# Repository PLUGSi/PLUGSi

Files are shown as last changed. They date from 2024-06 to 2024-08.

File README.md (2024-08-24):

# PLUGSi

## Smart Modular Power Outlet

## By <a href="https://github.com/danidudabare">Danidu Dabare</a>, <a href="https://github.com/miniMagic-beep">Mihiran Wickramarathne</a>, <a href="https://github.com/DinukaMadhushan1234">Dunuka Madushan</a>, <a href="https://github.com/kavinsiriwardana">Kavin Siriwardana</a>, <a href="https://github.com/SanujaRupasinghe">Sanuja Rupasinghe</a> 

## Licence


## URLs for Original GitHub Repos
- [PLUGSi GitHub Organization](https://github.com/PLUGSi)
- [PCB Repository](https://github.com/PLUGSi/PCB)
- [Documentation Repository](https://github.com/PLUGSi/Documentation)
- [Enclosure Repository](https://github.com/PLUGSi/Enclosure)
- [Unity-AR Mobile App Repository](https://github.com/PLUGSi/Unity-AR-mobile-app)

## Demo
https://github.com/user-attachments/assets/67be34dc-b150-4223-8576-c7e0ef582f0e

## PCB
For Each moduel Seperate PCBs were created.

### Modules
- plug_base
- timer_module
- set_timer_module
- wireless_switch_module
- bluetooth_module

### Base and Moduels images

<table>
  <tr>
    <td><br>Base</td>
  </tr>
  <tr>
    <td><br>Wireless Module</td>
    <td><br>Set Timer Module</td>
  </tr>
  <tr>
    <td><br>Reprogrammable Timer Module</td>
    <td><br>Bluetooth Module</td>
  </tr>
</table>

**Open PCB files using Altium PCB design software.**

## Enclosure
### Key Design Decisions
1. **Compact & Futuristic**
2. **Uniform Design**
3. **Modular Architecture**

### Prototype Images
  
  

## AR app
The PLUGSi AR app, developed with Unity, integrates augmented reality via the Vuforia SDK for image targeting and uses the MQTT protocol for IoT communication, all coded in C#.

### Key Features
- **Unity & Vuforia**: Built on Unity with Vuforia SDK for AR, enabling image-based tracking.
- **MQTT Protocol**: Facilitates communication with a broker for IoT control.
- **Add-ons Integrated**:
  - UI Button Pack 2
  - Safe Area Helper
  - Lean GUI
  - Lean Touch

### Screenshots
<table>
  <tr>
    <td><br>Base</td>
  </tr>
  <tr>
    <td><br>Wireless Module</td>
    <td><br>Set Timer Module</td>
  </tr>
</table>

## Documents
All the documetns related to different stages are provided in this repo

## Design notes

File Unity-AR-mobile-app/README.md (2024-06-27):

# PLUGSi AR App

The AR app is designed for the IoT-based module in PLUGSi.

## Overview

The app is built with the Unity game development platform, meaning it is a mobile app developed in Unity. Augmented reality is included using the Vuforia SDK with image targeting (Image Targets represent images that Vuforia Engine can detect and track).

The MQTT protocol is used to communicate with a broker. It is coded in C# within the Unity app scripts.

## Add-ons Integrated

The Unity app integrates several free add-ons:
1. UI Button Pack 2
2. Safe Area Helper
3. Lean GUI
4. Lean Touch

## App Pages

The Unity app has three pages:
1. **Intro Page**: Continuously running a video.
2. **Digital Twin Page**: Accessible via a button on the Intro page, it activates your camera to find the targeted image.
3. **Control Page**: With the camera on, this page features two buttons:
   - **PLUGSi**: Turns on/off the device connected to the base when the IoT module is connected. It also changes the digital twin's color to red or green to indicate the current status (On or Off).
   - **Start**: Returns you to the Intro page.

## Screenshots

AR1
AR2
AR3

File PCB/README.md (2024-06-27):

# PCBs

## Overview
This repository contains the PCBs of plug base and the modules that can be used with this plug base such as a programmable timer, set timer, wireless switch, and Bluetooth module. 

## Project Structure
The repository is organized as follows:

- `plug_base/`: Contains PCB files of plug base that the various modules will connect to.
- `timer_module/`: Contains PCB files of reprogrammable timer module.
- `set_timer_module/`: Contains PCB files of set timer module.
- `wireless_switch_module/`: Contains PCB files of wireless switch module.
- `bluetooth_module/`: Contains PCB files of Bluetooth module.

## Plug_Base
### Components
- **CD4041**: CMOS quad NAND Schmitt trigger inverter, used likely as an inverter or buffer.
- **Relay**: Electromagnetic switch controlled by an electrical signal to open or close contacts.
- **Resistors**: 10kΩ and 100kΩ resistors to limit current flow.
- **Capacitors**: Used to store electrical energy (value not shown).
- **Power Supply**: Provides voltage of 3V and VCC.
- **Module Connection (P2 and P3)**: Interfaces where the different modules plug into the base.

## Timer_Module
### Components
- **CD4011BE**: Quad NAND gate IC, likely used in the timer functionality.
- **Resistors (R1 and R2)**: Limit current flow (values determine current).
- **Capacitor (C1)**: Controls the timing interval by charging and discharging.
- **Pulse Input**: Trigger for the timer.
- **Output (OUT)**: Controls a relay or switching device for the outlet.
- **Status LED**: Indicates the timer state (on or off).
- **Trigger Input**: Used to reset or start the timer.

## Set_Timer_Module
### Components
- **IC1 (555 Timer)**: Functions as a voltage-controlled timer in a monostable configuration.
- **Resistors (R1 and R2)**: Work with C1 to determine timer duration.
- **Capacitor (C1)**: Sets the timer duration by controlling charge/discharge cycles.
- **Push Button (SW1)**: Trigger to initiate the timer.
- **LED1**: Visual indicator of timer status.
- **Output (OUT)**: Controls a relay or switching device for the outlet.

## Wireless_Switch_Module
### Components
- **IC1 (CD4017BE)**: CMOS IC with decade counter/divider stages, used to decode wireless signals.
- **Resistors (R1, R2, R3, R4)**: Limit current and set voltage levels.
- **Capacitor (C1)**: Filters noise on the power supply line.
- **Receiver (DI)**: Antenna or receiver circuit for the wireless signal.
- **Output (OUT)**: Controls a relay or switching device for the outlet.
- **Status LED**: Indicates the receiver module state (on or off).

## Bluetooth_Module
### Components
- **Microcontroller (U1)**: Controls the Bluetooth module and communicates with other devices.
- **Crystal (Y1)**: Provides precise oscillating signal for synchronization.
- **Resistors**: Limit current, set voltage levels, and bias transistors.
- **Capacitors**: Filter power supply, store energy, and provide stability.
- **Inductor (L1)**: Part of the matching circuit for the Bluetooth antenna.
- **Bluetooth Antenna**: Transmits and receives Bluetooth signals.
- **Status LED**: Indicates Bluetooth module state (powered on, connected, etc.).
- **Connection Pins (PBO - P5)**: Connect the Bluetooth module to the main plug base unit.

## Usage
### **Navigate to the Desired Module/PlugBase**:
  1. [`Plug Base`](./1.%20Plug%20Base)
  2. [`Reprogrammable Timer`](./2.%20Reprogrammable%20Timer)
  4. [`Set Timer`](./3.%20Set%20Timer)
  5. [`Wireless Switch`](./4.%20Wireless%20Switch)
  6. [`Bluetooth module`](./5.%20Bluetooth%20module)

### **Open the PCB Files**:
Use Altium PCB design software to open files.

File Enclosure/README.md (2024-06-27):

# Enclosure

Since the PLUGSi consists of main components: Base and Modules, and considering modular architecture, the following decisions were made:

1. **Try to make it as small as possible**
   - Give it a compact futuristic look
2. **Uniformity in Design**
   - All sides in the Base and Modules are the same size and cubic shape
   - Must be able to connect modules over the base and modules over modules
3. **General Architecture**
   - Modules have a general architecture with the same size as the Base
   - Design must accommodate multiple modules with minor changes to fit different functionalities

The initial design is available on [GrabCAD](https://grabcad.com/library/plugsi-1). We were unable to complete the design due to imperfections of 3D printers and the inability to make a very compact design by hand. For the ports, it should be 4 pin ports. Initial ideas were to make ports and 3D print them (which was hard to do). So we thought about other options like [4-Pin magnetic POGO connections](https://kamami.pl/en/pogo-pin/1181255-pair-of-4-pin-magnetic-connectors-straight.html) and the [4-Pin magnetic POGO connections 3D models](https://grabcad.com/library/pogo-pins-ports-1). For the prototype, we used 4-Pin JST connections.

We have designed a prototype version of the PLUGSi enclosure which is done by laser cutting of acrylic.

## Prototype Images
Images taken from SolidWorks and Rendered images from blender are available here.








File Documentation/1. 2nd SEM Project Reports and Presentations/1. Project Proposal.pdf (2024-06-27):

# Engineering Design Project

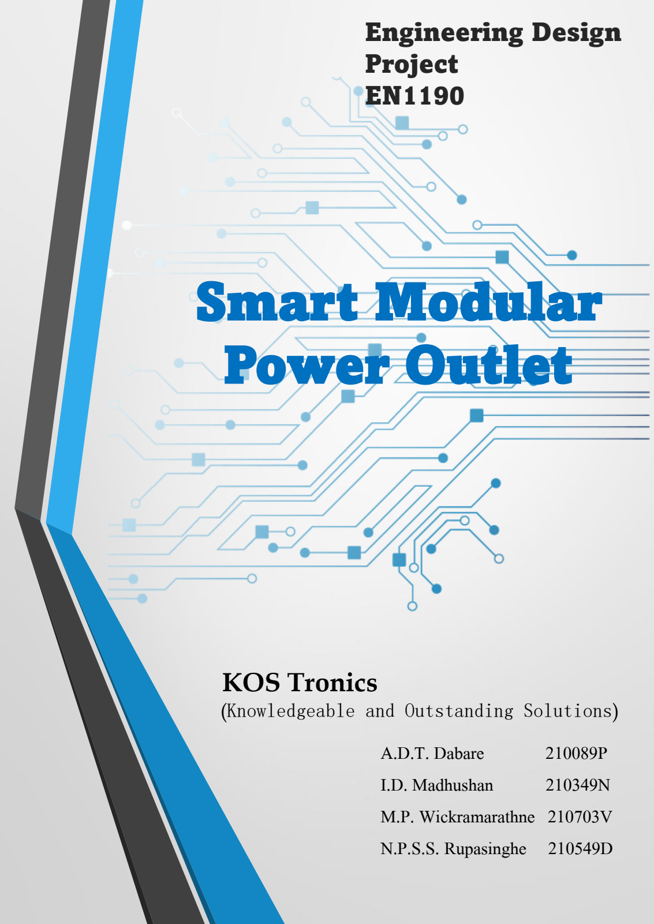
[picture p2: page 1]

EN1190

# KOS Tronics

### (Knowledgeable and Outstanding Solutions)

# Smart Modular Power Outlet

A.D.T. Dabare | 210089P
I.D. Madhushan | 210349N

# M.P. Wickramarathne 210703V N.P.S.S. Rupasinghe 210549D

### Problem

The current world is embracing smart technologies but majority of the devices we encounter does not have those capabilities. And there are no smart power outlets that are up to a level to be called smart. The existing solutions are neither customizable, repairable nor upgradable and does not have a robust design. When purchasing smart outlets, users currently have to pay for all the features even though they only need a specific function.

### Solution

The solution we propose is a smart modular power outlet to which the user can attach modules as needed. In our proposed solution, users can get the smart power outlet base for a low price and then add up the required and additional modules as needed.
Example : If the user needs to turn on a fan via the Bluetooth, then they have to buy a smart fan(quite expensive) or to buy an existing smart power outlet which has so many other additional features that are not needed for the purpose.

Manufacturing a purpose specific solution can be costly because number of products is small but manufacturing a general solution that can be made purpose specific is ideal for that problem.

### Working Principle

The device is consisted of two main parts.
- Main Base
- Modules
Main Base will be connected to a power outlet and any utility can be connected to it. Main base will control the AC supply to the utility and provide power to modules. Main base will have a port(interface) to communicate with the modules.
Modules can be attached to and detached from the Main Base. Modules will control the state of the Main base. Modules can have a variety of abilities based on their design. Multiple modules can be connected to the same Main Base.

Some examples for Modules
- Bluetooth Module
- Timer Module
- PIR Module
- Temperature sensing Module

### How it stands out

- Customizability
- Comparatively low cost
- Can be a tool for other developments
- High Repairability
- Can be made purpose specific

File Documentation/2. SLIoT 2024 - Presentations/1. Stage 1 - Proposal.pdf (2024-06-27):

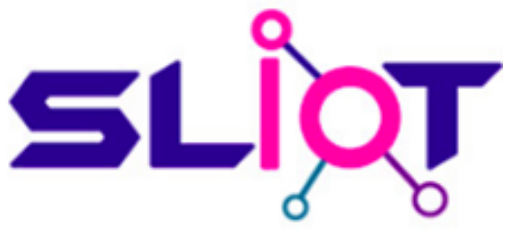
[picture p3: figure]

# PLUGSi Smart Modular Power Outlet

# Project Proposal

Team Name | PLUGSi
Category | UNDERGRADUATE
Theme | INDUSTRY 4.0

# Problem Definition

## Introduction

Our team noticed that the existing power outlets are not advanced enough to match the level of technological advancement in the current world. Although there are many smart appliances, power outlets that can actually be called smart are not available on the market. The problem we identified is that the existing power outlets do not have customizable add-ons such as Bluetooth, Wi-Fi, Reprogrammable Timers, Set Timers, etc. nor intelligent decision-making abilities. They either cater to only their core function or have add-ons that come with it originally eliminating the ability to customize them according to the needs of the user making them highly expensive. Therefore, we conducted a survey to get detailed user inputs and what follows are the reasons for the existing options to be disliked by users. We aim to resolve the following concerns by addressing our main identified problem emphasized above.

We conducted a survey and following are the results.

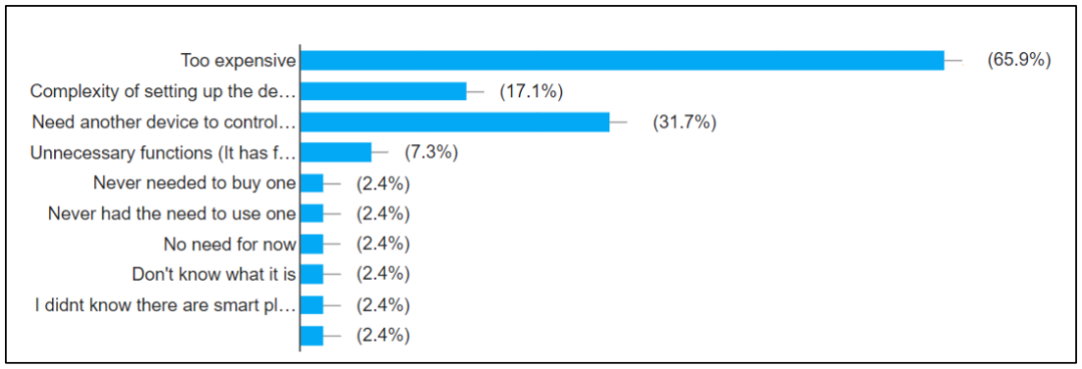
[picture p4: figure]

## Problem Analysis

In the rapidly advancing landscape of smart technologies, where IoT and automation are transforming daily life, the stagnation in smart power outlets is a bottleneck. The identified problem holds implications across various sectors: both domestic and industrial. Domestic consumers are increasingly adopting smart home technologies, yet the current limitations in smart power outlets hinder their full potential. In industrial settings, the lack of advanced power outlets results in missed opportunities for automation and optimization. By incorporating IoT through a mobile application into smart power outlets, we can enable dynamic communication, allowing for advanced automation and intelligent decision-making based on real-time data. Our proposed solution aligns with the paradigm of Industry 4.0 as we look into Integrating IoT, AI, and automation into the development of customizable smart power outlets. AI algorithms can learn user behavior, optimize energy usage, and adapt to changing patterns.

# Proposed Solution

## Proposed Product

The product consists of two main parts.
- Power Base
- Modules

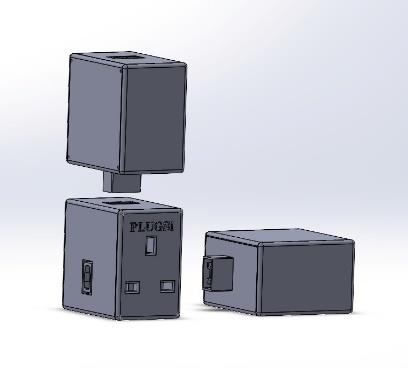
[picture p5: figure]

Modules can be attached to and detached from the Power Base. Modules control the state of the power base. They can have a variety of abilities based on their design. Multiple modules can be connected to the same Power Base. Bluetooth Module, Reprogrammable Timer Module, Set Timer Module, and Wireless Switch are some examples for Modules.

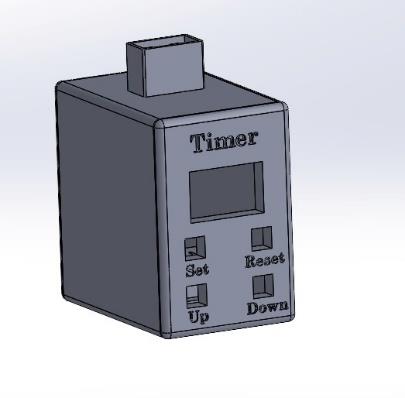
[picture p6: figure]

Power Base is connected to a power outlet and any utility (device) can be connected to the Power Base. It controls the AC supply to the device and provide power to modules. Power Base has ports(interfaces) to communicate with the modules.

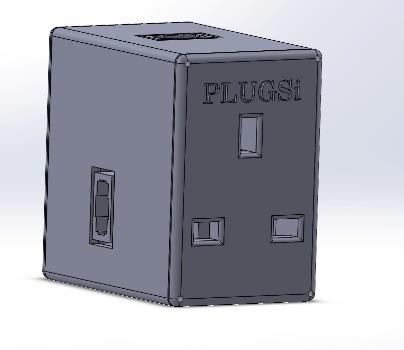
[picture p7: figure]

## Uniqueness of the Solution

In our solution, users can choose the modules that they need rather than paying for all the unnecessary functions. We can provide instructions as to how the Power Base works and the requirements that a module needs so that anyone can make their own modules. Further, it uses a standardized communication protocol, ensuring seamless integration. Its affordable power base provides a cost-effective entry point, while allowing third parties to develop modules. Its unique modular design enables users to swap modules based on their interests or changing needs, promoting adaptability. This is an eco-friendly solution as this minimizes electronic waste. In essence, the Smart Modular Power Outlet redefines user experience with affordability, adaptability, modularity, and customizability.

# Technical Overview and Implementation

## Technical Details

The module is designed to issue a command using a pulse signal, and it performs a status check prior to generating the pulse signal. In the event that the power base has reserved a pulse, the base modifies the current state of the relay. This functionality is achieved through the implementation of a pulse-based communication protocol and the integration of status monitoring and relay control mechanisms within the module's architecture.

Module’s hardware will be based on their own designs to achieve the required outcome. All of them would share a mechanism to check the base status and generate the pulse.

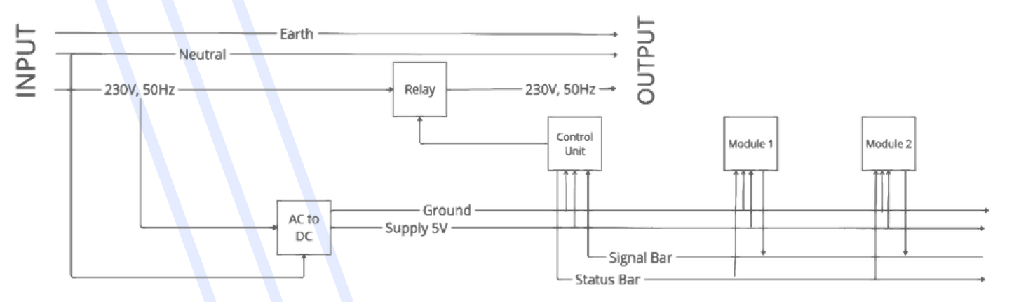
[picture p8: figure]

# User Scenario

Scenario 1
Industrial facilities often require control over the power supply to numerous machines for maintenance, energy management, and process optimization. Currently, existing options fall short:
- They have to rely on existing smart plug which comes with load of unnecessary features with a high price
- They have to build a power outlet from the scratch

Solution: PLUGSi, the modular smart plug, revolutionizes industrial machine control with its flexible and scalable approach with low cost. They just have to use PLUGSi base with the Bluetooth module. Even it is possible to upgrade PLUGSi when needed with such as IoT features, timers etc.

Scenario 2
Thaveesha wants to control his water pump by a remote control and turn it off automatically after 10 minutes. There is no popular solution for him in current market. He has to buy something which can be very expensive and not suitable to the scenario.

Solution: Thaveesha only has to get the PLUGSi base, Timer module, And IR module with Remote controller. And now he has achieved his goal. Hooray. He has the possibility of upgrading to or use PLUGSi with a completely different use case.

Scenario 3
The power outlet modules can be equipped with energy monitoring capabilities. Residents can track and analyze the energy consumption of individual devices plugged into these outlets through a dedicated mobile app or a centralized smart home hub using digital twin technology.

Scenario 4
Some power outlet modules can include built-in occupancy sensors. If no motion is detected in a room for a specified period, the outlets can automatically cut power to connected devices to prevent unnecessary energy consumption and reduce the risk of electrical fires. Smart outlets can be integrated with home security systems. For example, when the security system is armed, the outlets can automatically cut power to non-essential devices, creating the appearance that nobody is home.

# Team Details

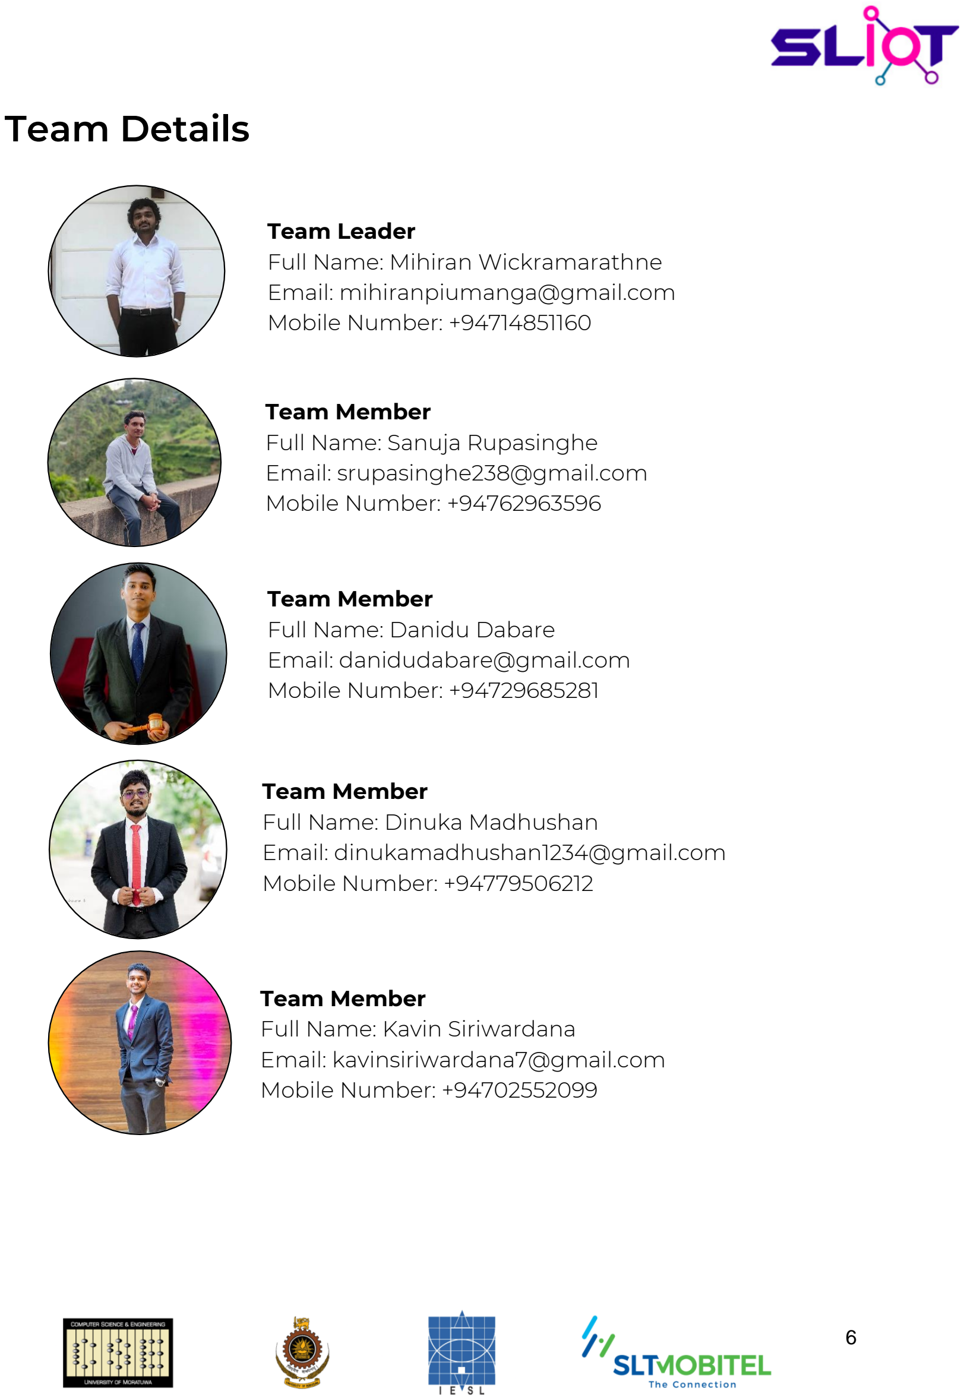
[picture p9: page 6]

Team Leader
Full Name: Mihiran Wickramarathne Email: mihiranpiumanga@gmail.com Mobile Number: +94714851160

Team Member
Full Name: Sanuja Rupasinghe Email: srupasinghe238@gmail.com Mobile Number: +94762963596

Team Member
Full Name: Danidu Dabare
Email: danidudabare@gmail.com Mobile Number: +94729685281

Team Member
Full Name: Dinuka Madhushan
Email: dinukamadhushan1234@gmail.com Mobile Number: +94779506212

Team Member
Full Name: Kavin Siriwardana Email: kavinsiriwardana7@gmail.com Mobile Number: +94702552099

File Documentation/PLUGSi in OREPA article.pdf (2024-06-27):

# PLUGSi

The Modular Smart power outlet

Begin
PLUGSi is a way that can be used to revolutionize the way we think about power outlets

Introduction - Who We Are
We are 4 undergraduates from the Electronic and Telecommunication Department of the University of Moratuwa. For our Electronic Design Project module, We proposed this Idea and executed it.

Philosophy - modularity
Modularity is a philosophy not used in the current smart power outlet industry. You may see a cube-looking thing. called a “smart power outlet” (which is indeed smart) containing everything inside it (Maybe Alexa, Google Home, timers, Bluetooth Controllers, Wi-Fi controllers) to control a few things. Your Table Lamp, AC, something else. Some are Product Specific, and Some give additional functionality that you’ll never use but you paid extra money for it.

Use Case
Assuming you are a smart plug user, one day your girlfriend comes to your home, and She wants to control the light that is plugged into your smart plug only using Bluetooth. What if your Smart plug does not support that functionality? You have few options. Change your Girlfriend 😅 (be careful) or buy a new smart plug that has Bluetooth support 💰 (may be somewhat expensive).
But with PLUGSi You have to do neither. Because we are giving you another option.

Functionality - base, modules, and apps
PLUGSi consists of 2 main parts. Base and modules (timers module, Wireless module, Wi-Fi modules, Bluetooth modules, IOT-based modules, Alexa Modules, reprogrammable Modules, etc) You can plug modules over the base and modules over other modules, it's your choice. Modules are the ones that add functionalities to the base. Users can attach detach and reattach as they wish. That other option is if you already have a PLUGSi base. Just buy a Bluetooth module. Save your money and your girlfriend!

We made a prototype for the demonstration - MVP

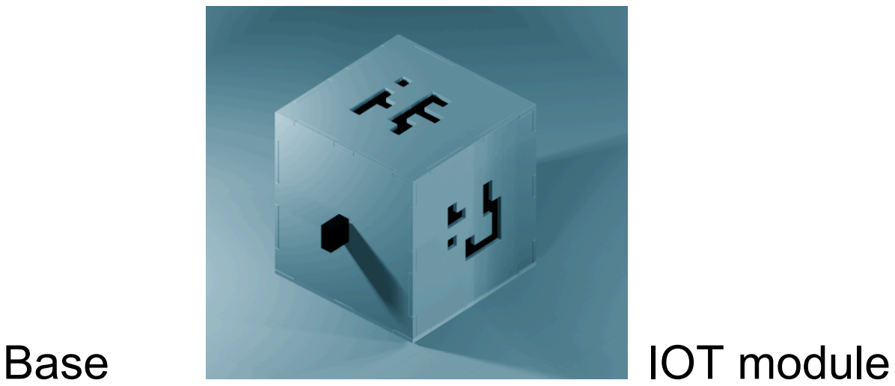
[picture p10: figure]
Base; IOT module
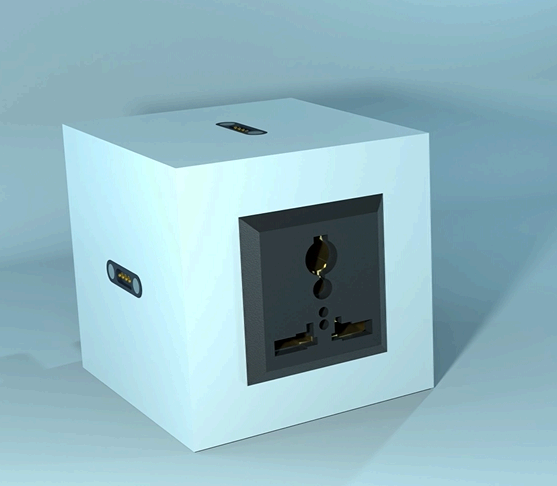
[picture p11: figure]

Base PCB

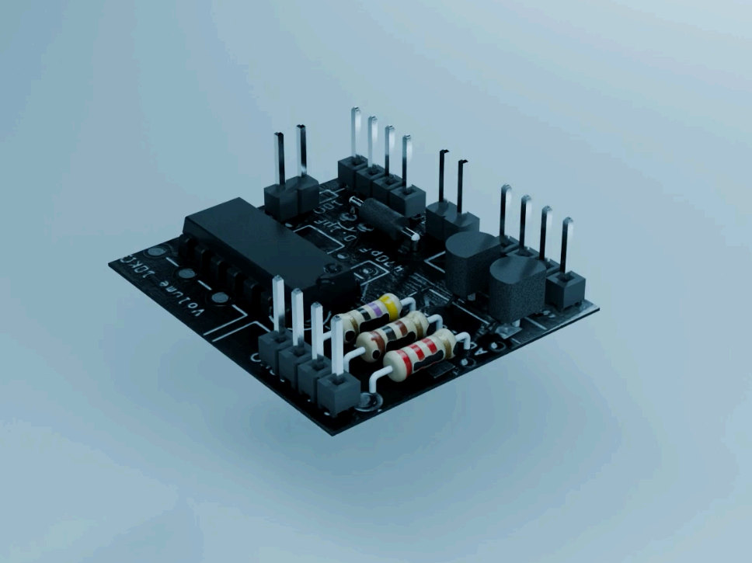
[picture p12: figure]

Architecture of the product

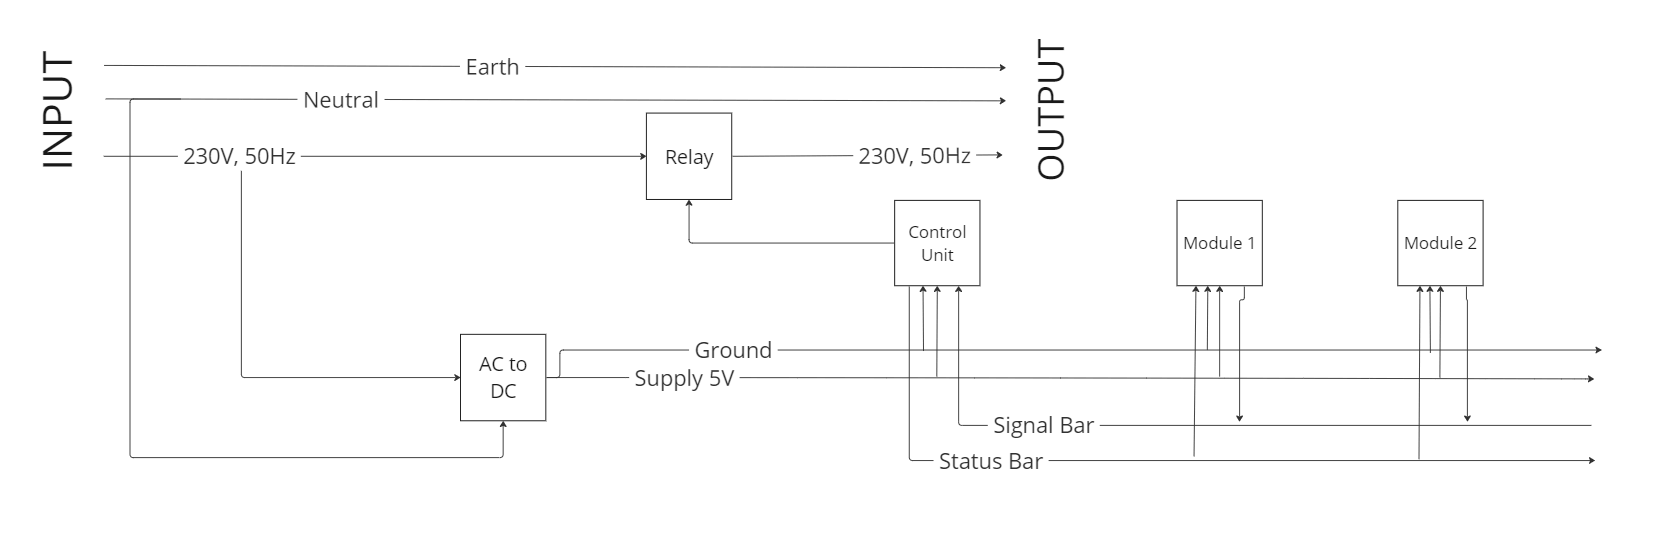
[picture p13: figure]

About Modules

For the Bluetooth module, we will provide the users with a Bluetooth app from Play Store.
For the IOT module, we will provide the users with a web dashboard, and an App that gives a brand-new user experience (a Digital twin) by giving them a Virtual representation of the IOT module with Augmented reality.
We made timer modules also (with 5min Fixed timer and timer that we can select the time)

this is for IOT app

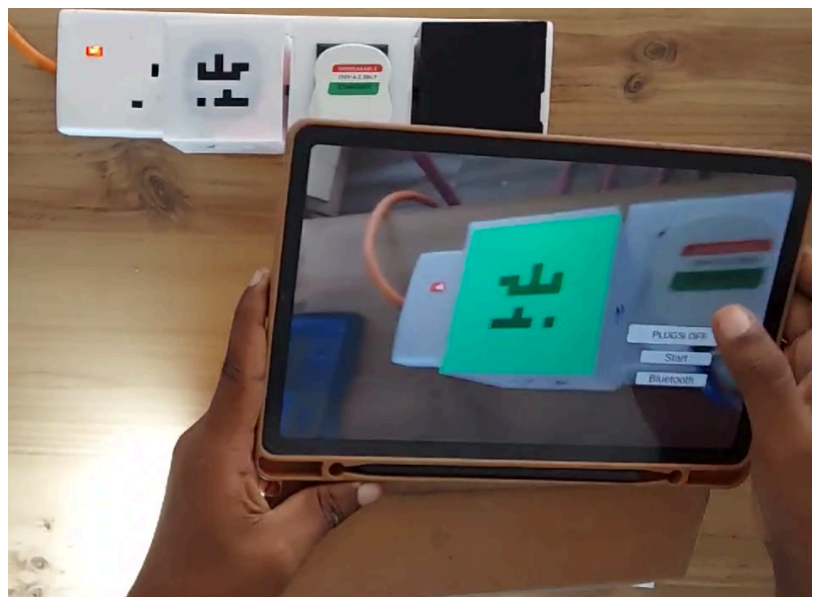
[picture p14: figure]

(This is not the end product. This is just for the prototyping MVP)

For the IOT part, we are using the standard communication protocol MQTT which is used in the IOT industry. We made a pulse communication protocol that communicates between the Base and Modules from scratch.

For whom did we make it?
Current smart plugs focus on just only smart home systems and automation. Of course, that is one of our targets. And we will give a safe environment to the DIY community so they can develop over our PLUGSi.
You may have seen that there are hundreds of thousands of Videos on YouTube tutorials that teach how to use Arduino-related things, relays and so many things to make your home smart. If you are a parent you may not allow your child to do those things because there is an issue about the safety of your child. Because the child has to work with an AC line which needs good guidance.
But with PLUGSi we are providing a fully functioning Base. No worries about the AC line, Even a 5-year-old can build and automate their house by buying a Base and Reprogrammable Module. We will provide them with a simple IDE so they can drag and drop the functions and program that module safely and do anything that they like.
And 3rd parties will be able to make modules and then they can be a part of a the PLUGSi ecosystem.

End
To achieve infinite modularity, simplicity, unlimited customizability, and adaptability there is no

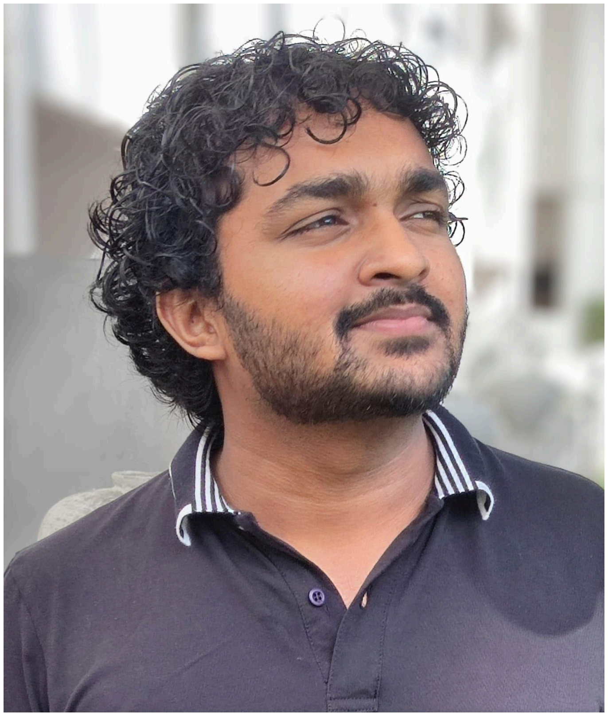
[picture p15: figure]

way other than PLUGSi.

Our Team

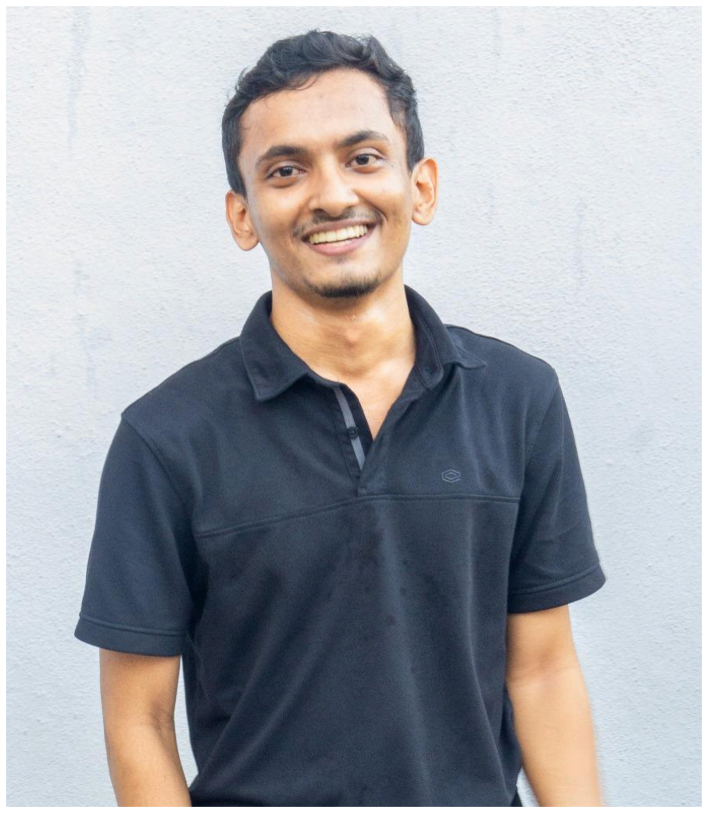
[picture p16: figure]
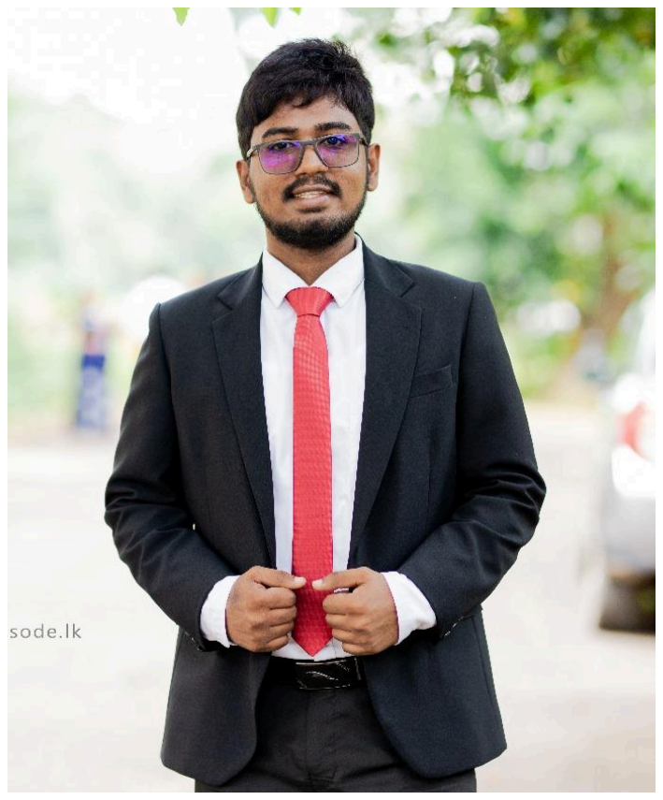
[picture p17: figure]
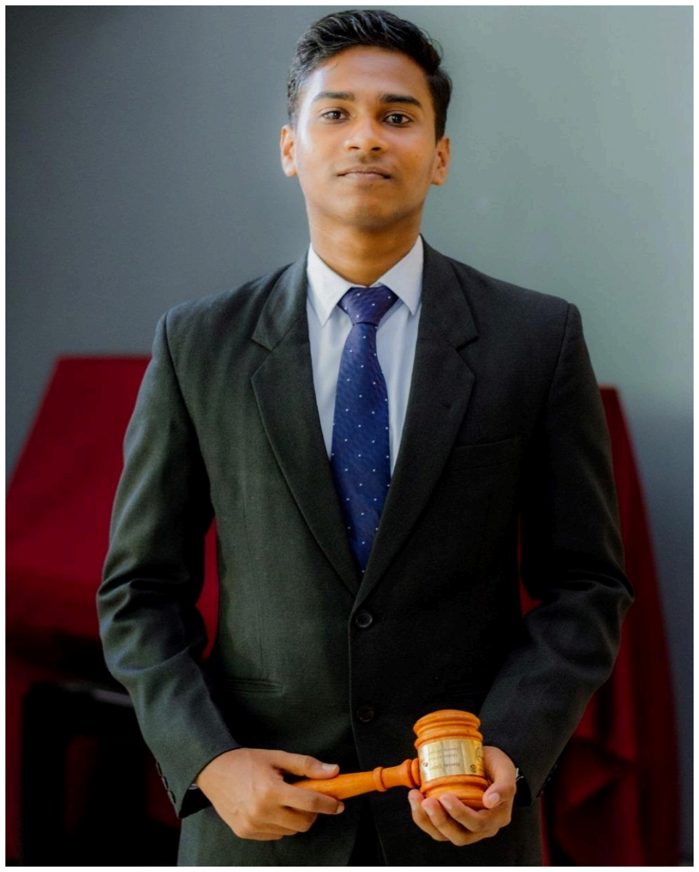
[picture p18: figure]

Mihiran | Sanuja | Dinuka | Danidu

Achievements
Finalists at INSL Sri Lanka Business Stage 2024 Semi-Finalists at SLIoT Challenge 2023

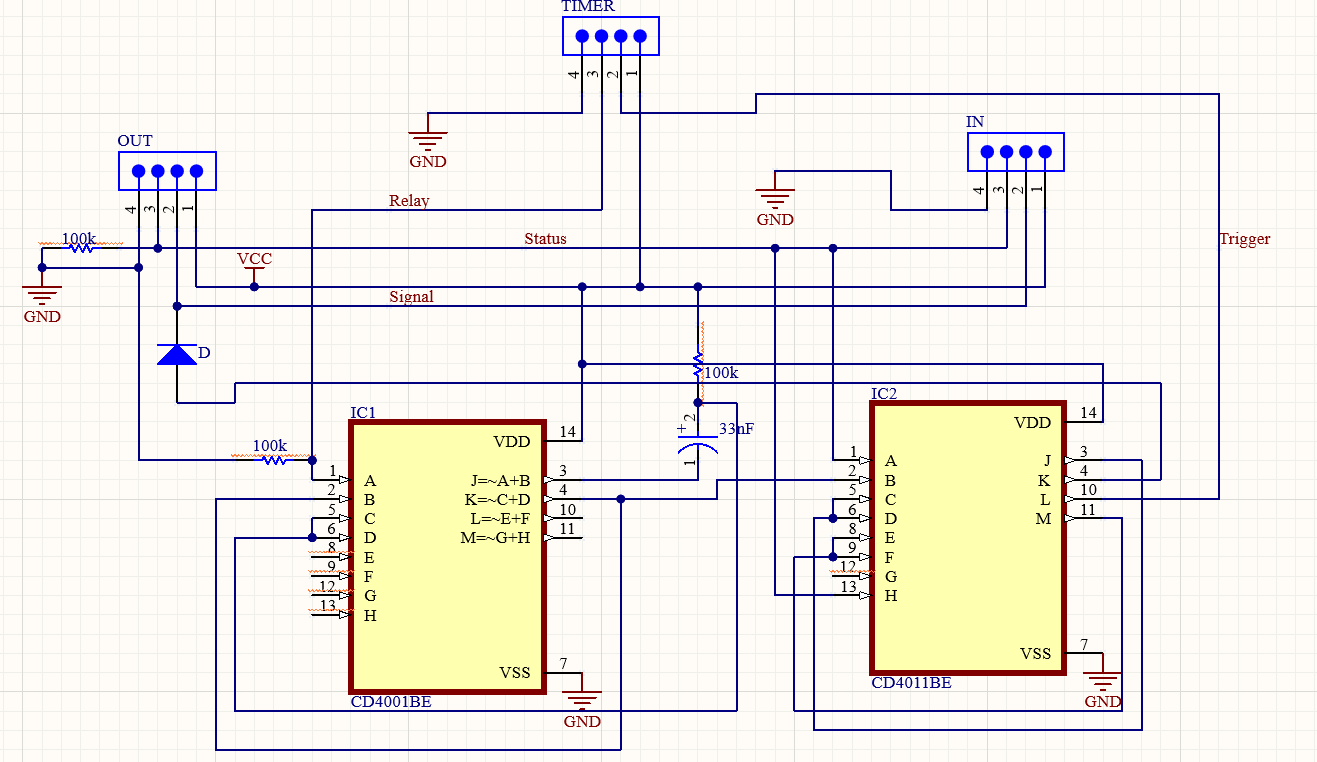
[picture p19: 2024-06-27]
PCB/2. Reprogrammable Timer/Timer Schematic.png

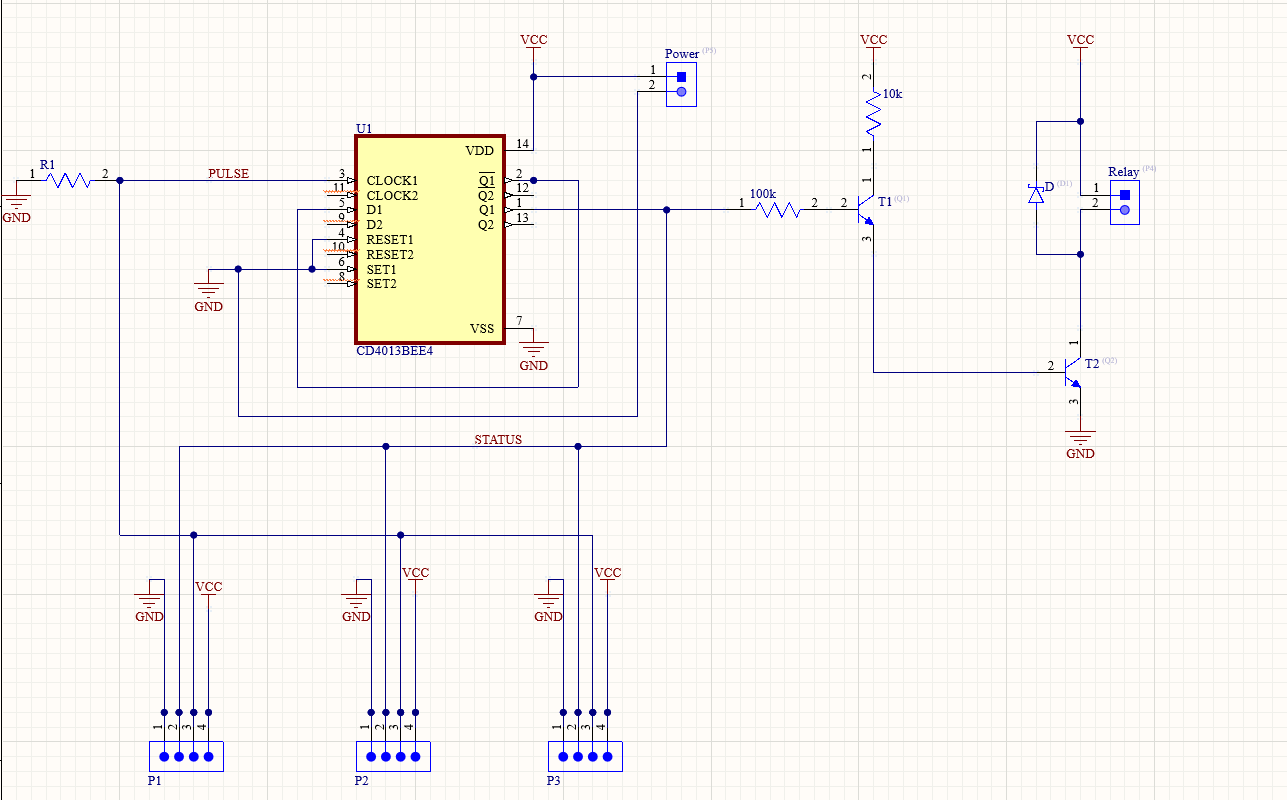
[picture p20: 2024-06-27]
PCB/1. Plug Base/Plug Base Schematic.png

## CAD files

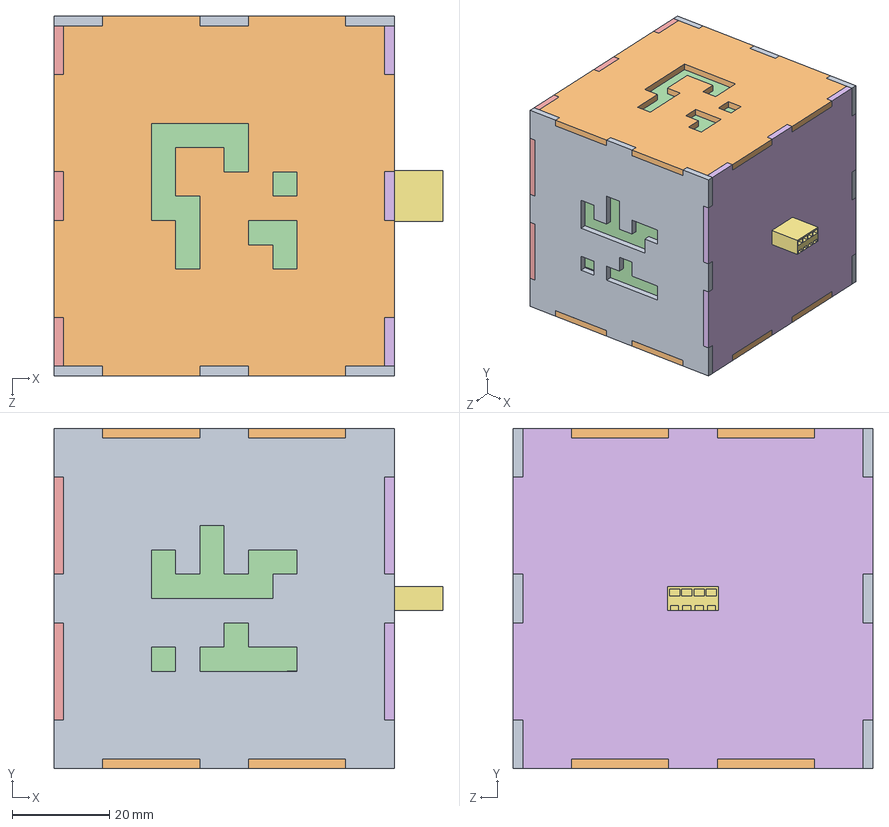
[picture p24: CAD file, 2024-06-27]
Enclosure/Module/Module_Assem.SLDASM
80.0 x 70.0 x 74.0 mm
Module_Front x 2
Module_TB x 2
fixer x 4
Black_Cover x 4
Module_LR_Female
Module_LR_Male
port_1
port_2

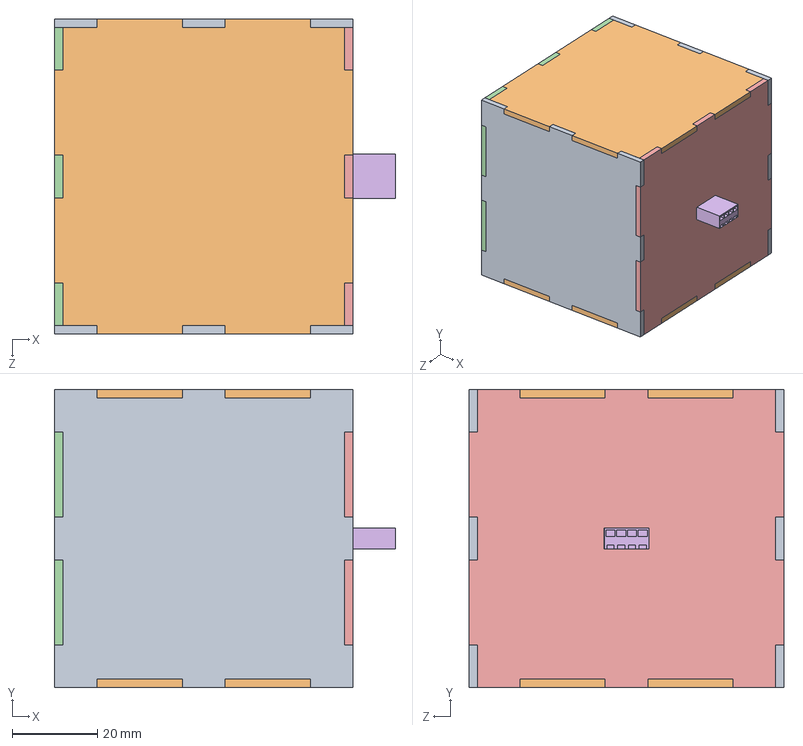
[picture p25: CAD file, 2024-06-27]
Enclosure/Module_Normal/Module_Assem.SLDASM
80.0 x 70.0 x 74.0 mm
Module_Front x 2
Module_TB x 2
fixer x 4
Module_LR_Female
Module_LR_Male
port_1
port_2

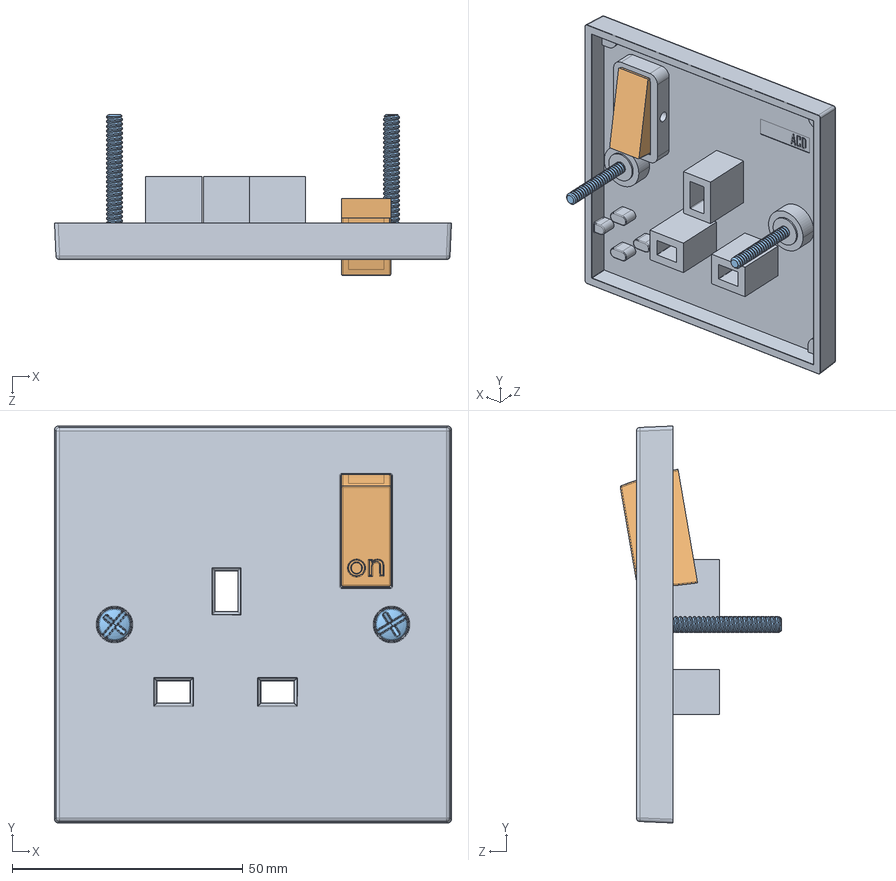
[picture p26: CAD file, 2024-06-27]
Enclosure/Base/UK plug/Plug Socket UK 13 STEP.STEP
86.0 x 86.0 x 35.0 mm
Plug Fascia
Switch
Main Screw x 2

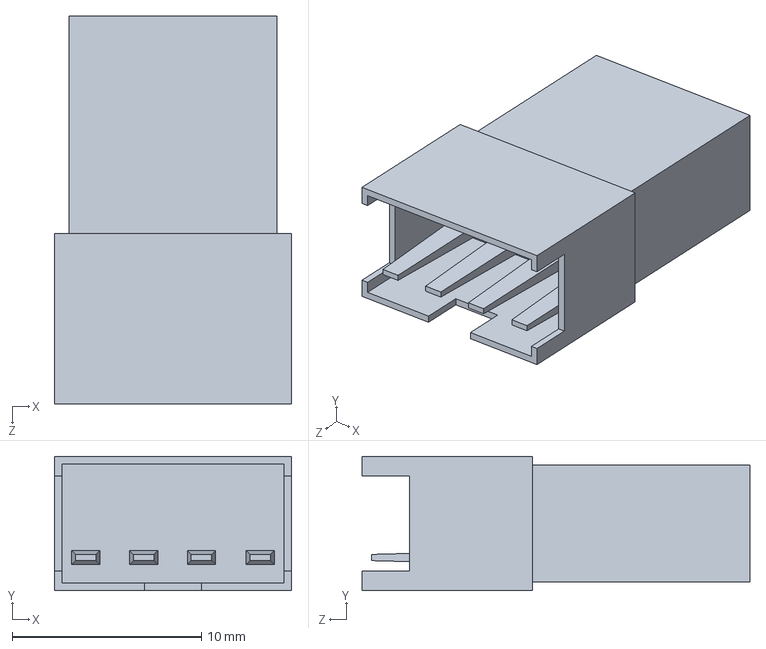
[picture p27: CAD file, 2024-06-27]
Enclosure/Module/port_2.SLDPRT
12.5 x 7.10 x 20.5 mm

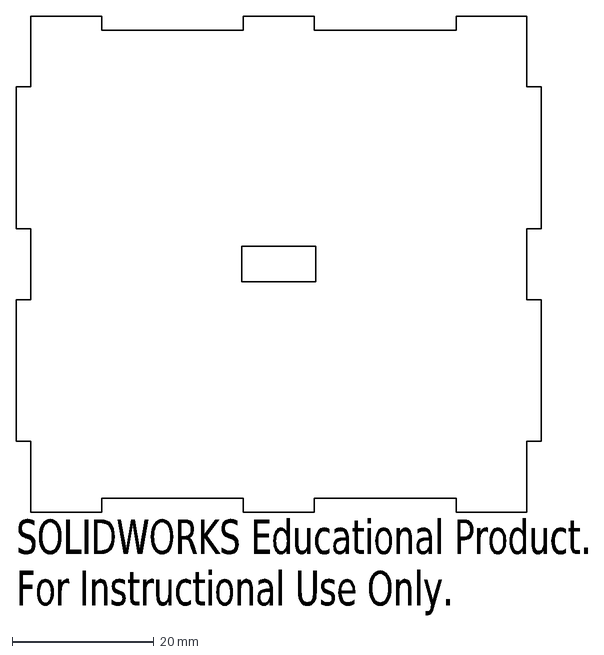
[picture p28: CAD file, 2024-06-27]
Enclosure/Module_Normal/DXF/Black/Module_LR_Male-1.DXF
SOLIDWORKS Educational Product.
For Instructional Use Only.

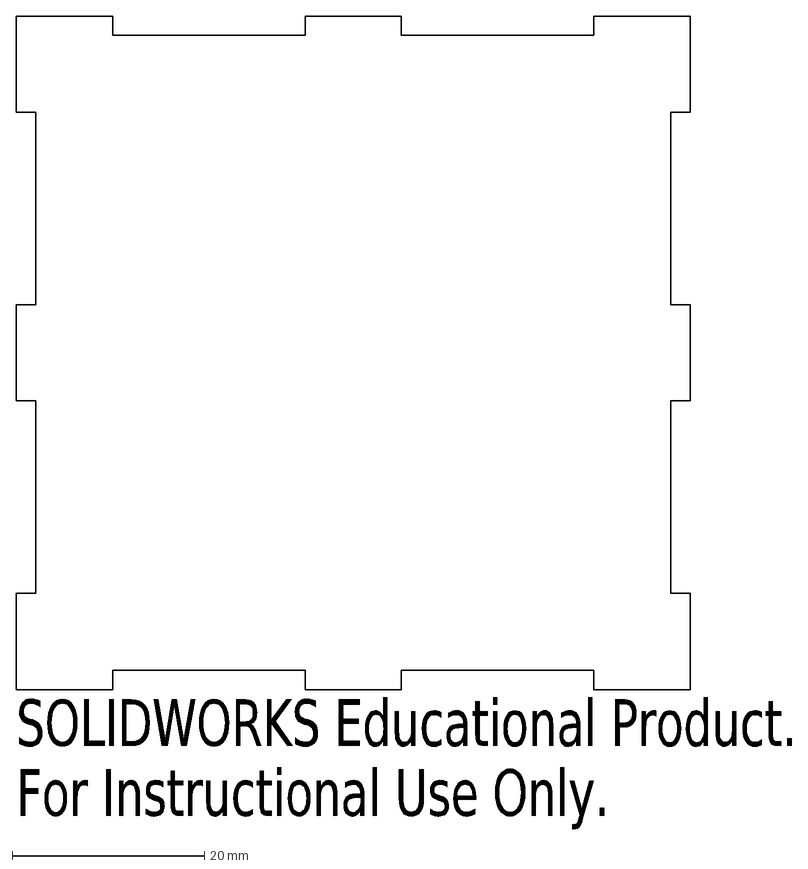
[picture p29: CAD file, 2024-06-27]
Enclosure/Module_Normal/DXF/White/Module_Front-2.DXF
SOLIDWORKS Educational Product.
For Instructional Use Only.

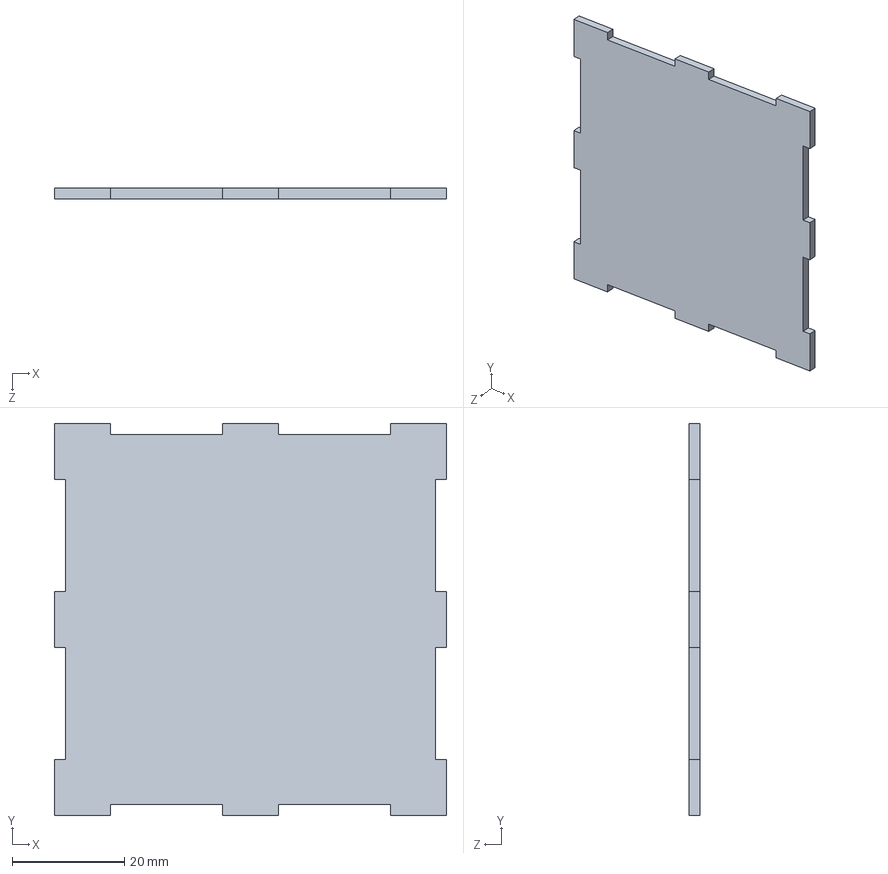
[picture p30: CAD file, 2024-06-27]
Enclosure/Module_Normal/Module_Front.SLDPRT
70.0 x 70.0 x 2.00 mm

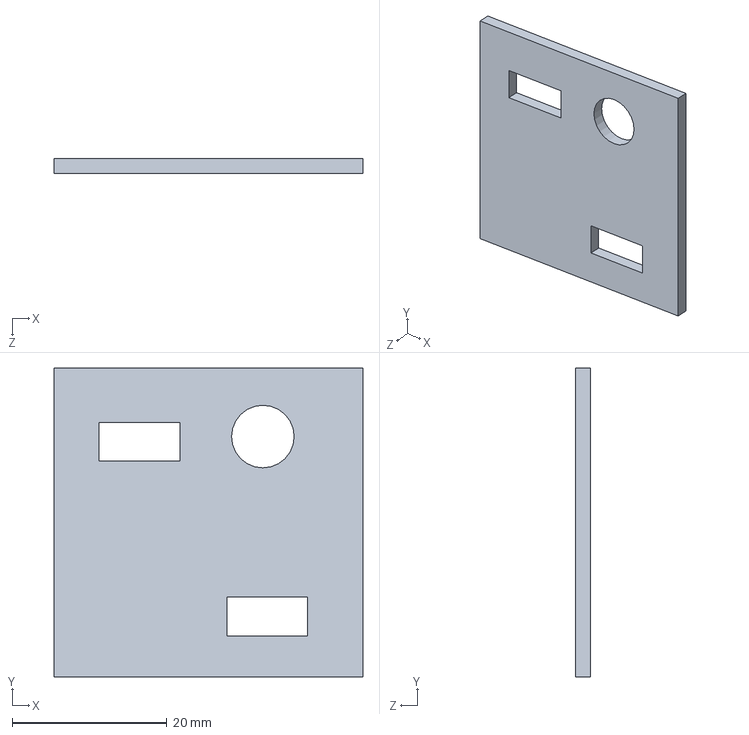
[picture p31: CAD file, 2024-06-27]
Enclosure/Module_Normal/test/Part1.SLDPRT
40.0 x 40.0 x 2.00 mm

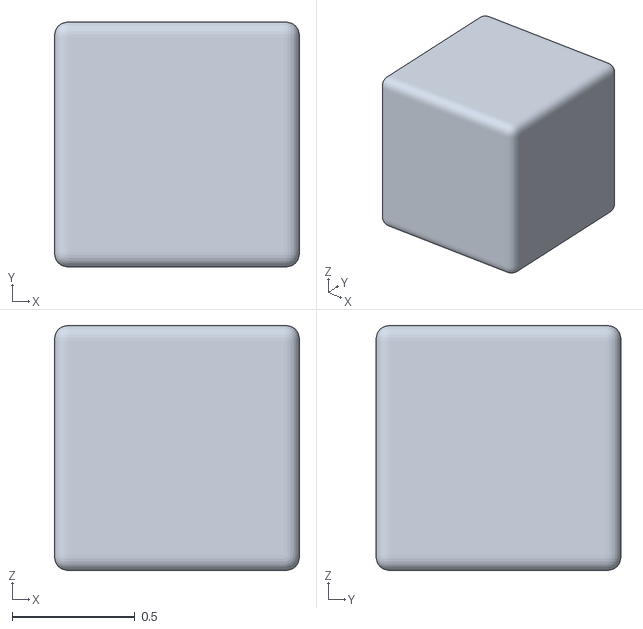
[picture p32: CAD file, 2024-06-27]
Unity-AR-mobile-app/PLUGSi_AR_App/Assets/Plugins/CW/LeanCommon/Examples/Meshes/RoundedCube.obj
1.00 x 1.00 x 1.00

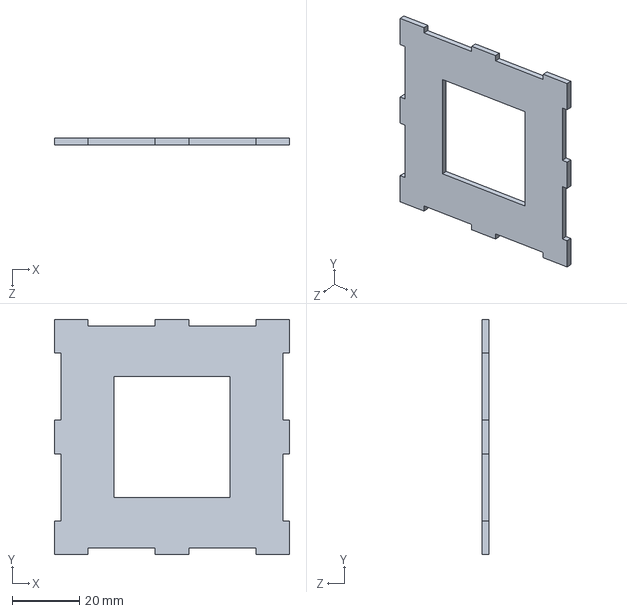
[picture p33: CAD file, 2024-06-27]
Enclosure/Base/Base_Front.SLDPRT
70.0 x 70.0 x 2.00 mm

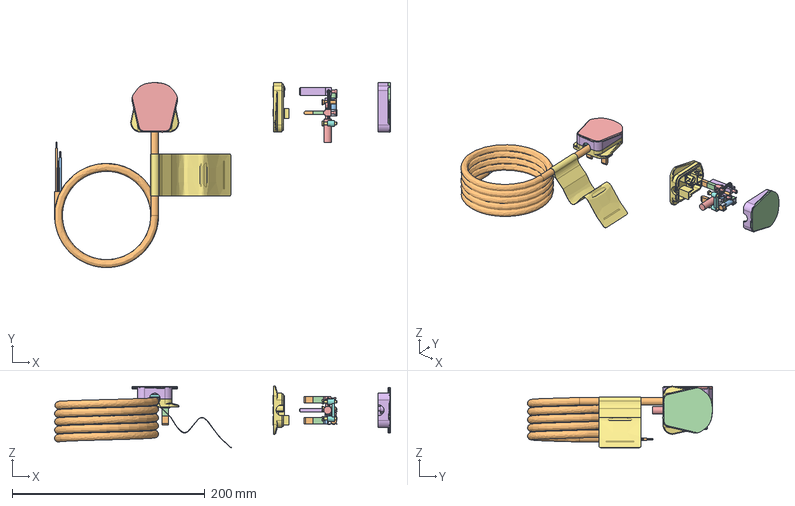
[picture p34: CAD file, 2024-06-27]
Enclosure/Base/UK plug/UK 3 PIN PLUG.stp
348.5 x 192.0 x 64.0 mm

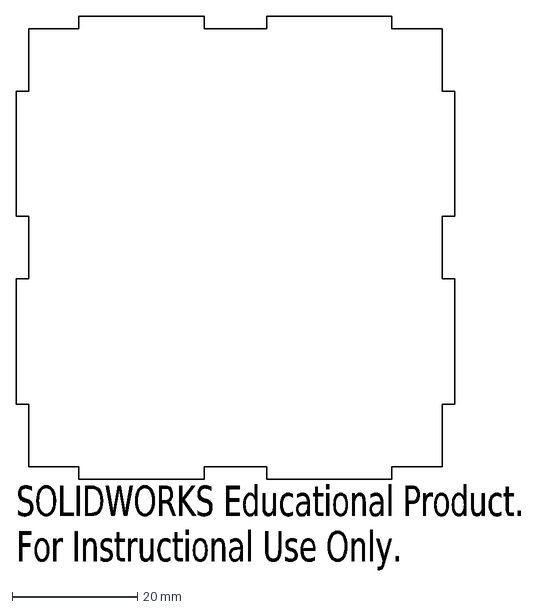
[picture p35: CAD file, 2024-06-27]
Enclosure/Module_Normal/DXF/Black/Module_TB-2.DXF
SOLIDWORKS Educational Product.
For Instructional Use Only.

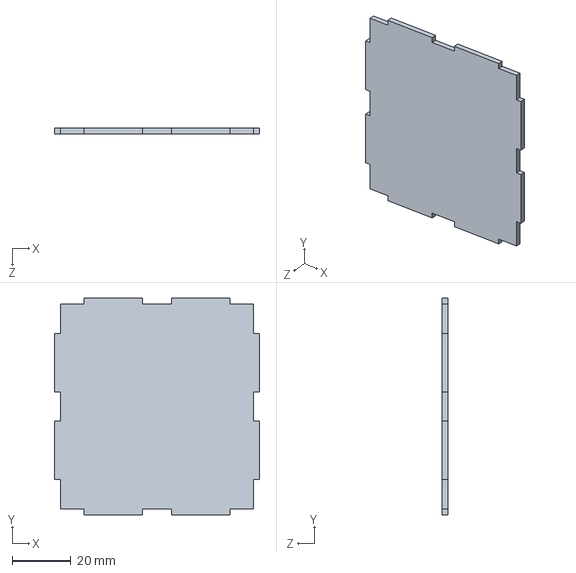
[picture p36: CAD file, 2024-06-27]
Enclosure/Module_Normal/Module_TB.SLDPRT
70.0 x 74.0 x 2.00 mm

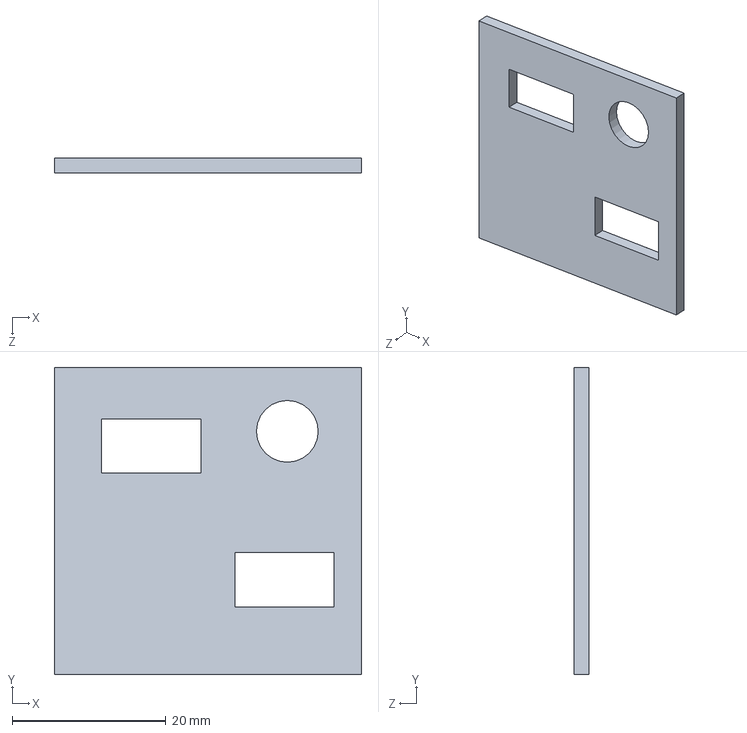
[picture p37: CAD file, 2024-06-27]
Enclosure/Module_Normal/test/Part3.SLDPRT
40.0 x 40.0 x 2.00 mm

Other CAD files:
Enclosure/Base/Base_LR.SLDPRT
Enclosure/Module/Module_LR_Female.SLDPRT
Enclosure/Base/220ACto5VDC.SLDPRT
Enclosure/Base/Base_Back.SLDPRT
Enclosure/Base/Base_LR_Pogo_Port.SLDPRT
Enclosure/Base/Base_Plug_Front.SLDPRT
Enclosure/Base/Base_TB - Copy.SLDPRT
Enclosure/Base/Base_TB.SLDPRT
Enclosure/Module/Black_Cover.SLDPRT
Enclosure/Module/Module_Back.SLDPRT
Enclosure/Module/Module_Front.SLDPRT
Enclosure/Module/Module_LR.SLDPRT
Enclosure/Module/Module_LR_Male.SLDPRT
Enclosure/Module/Module_TB.SLDPRT
Enclosure/Module/fixer.SLDPRT
Enclosure/Module/port_1.SLDPRT
Enclosure/Module_Normal/Black_Cover.SLDPRT
Enclosure/Module_Normal/DXF/Black/Module_LR_Female-1.DXF
Enclosure/Module_Normal/DXF/White/Module_LR_Female-1.DXF
Enclosure/Module_Normal/Module_Back.SLDPRT
Enclosure/Module_Normal/Module_LR.SLDPRT
Enclosure/Module_Normal/Module_LR_Female.SLDPRT
Enclosure/Module_Normal/Module_LR_Male.SLDPRT
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

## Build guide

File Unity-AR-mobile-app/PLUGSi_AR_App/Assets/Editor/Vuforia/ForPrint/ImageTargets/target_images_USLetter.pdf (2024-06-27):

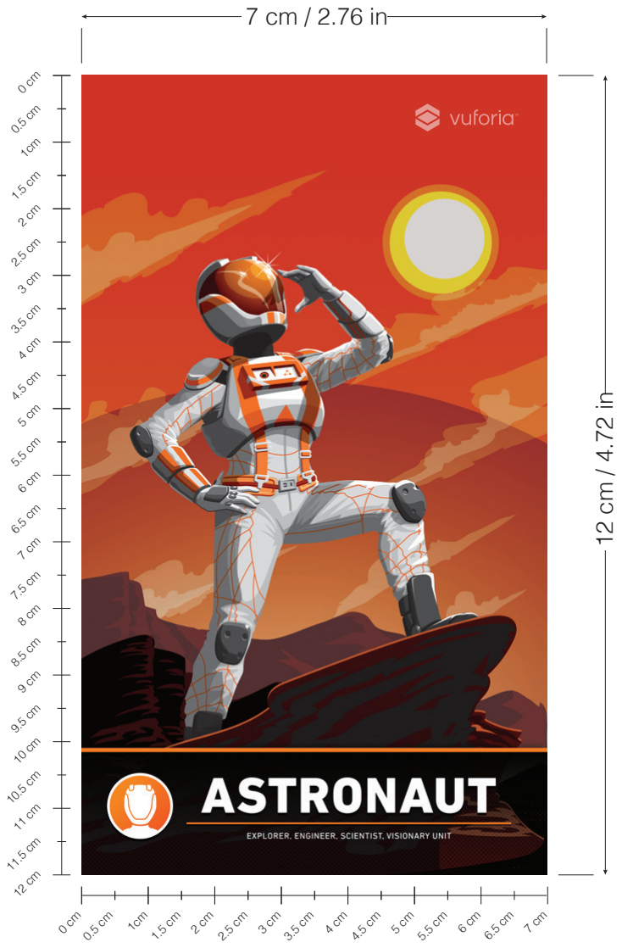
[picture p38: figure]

©2017 - 2018 PTC Inc. All rights reserved.

For best results, please print without scaling.

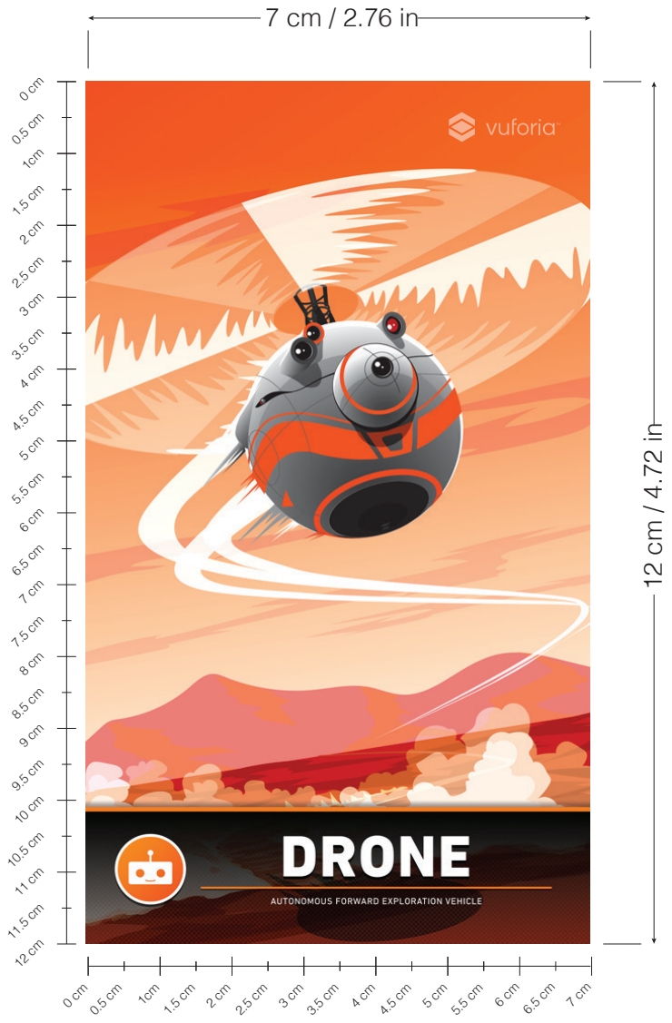
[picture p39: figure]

©2017 - 2018 PTC Inc. All rights reserved.

For best results, please print without scaling.

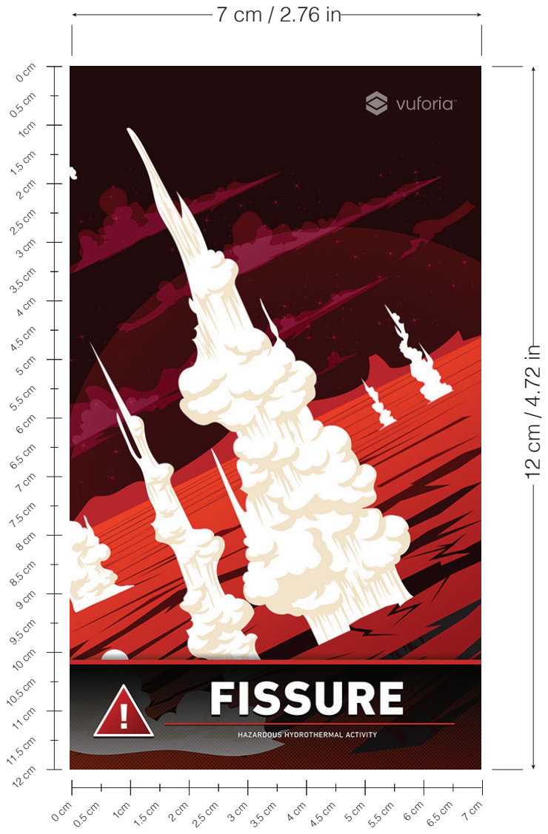
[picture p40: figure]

©2017 - 2018 PTC Inc. All rights reserved.

For best results, please print without scaling.

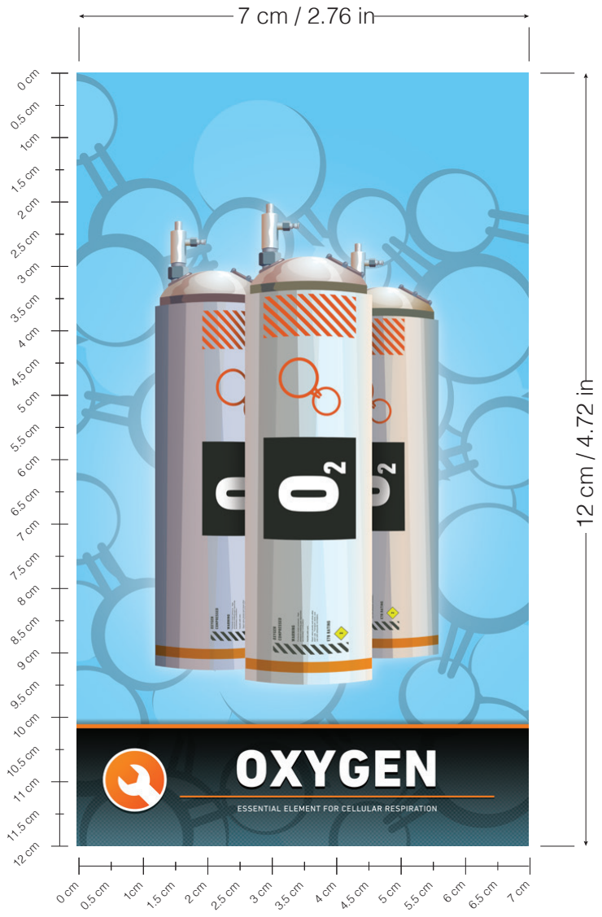
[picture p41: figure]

©2017 - 2018 PTC Inc. All rights reserved.

For best results, please print without scaling.

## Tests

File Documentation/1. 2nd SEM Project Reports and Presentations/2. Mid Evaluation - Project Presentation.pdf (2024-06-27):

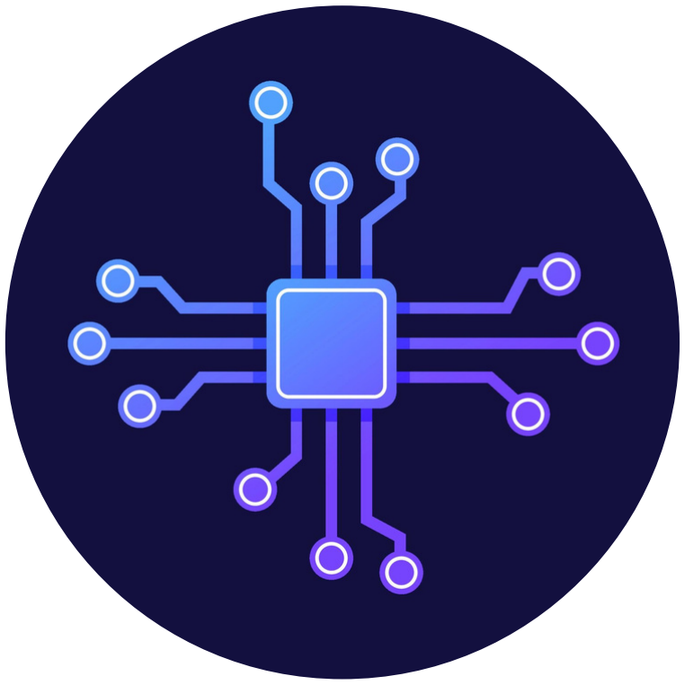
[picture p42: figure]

PRESENTED BY
KOS TRONICS

# PLUGSi

Smart Modular Power Outlet

# Team KOS Tronics

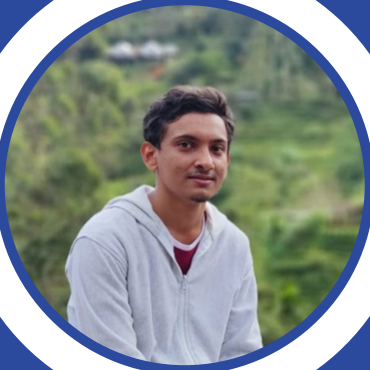
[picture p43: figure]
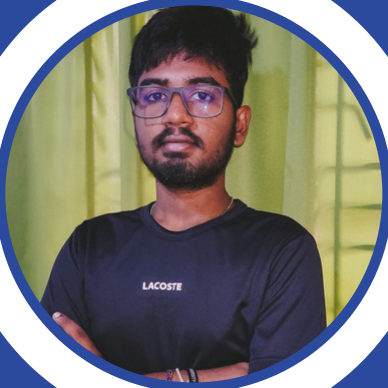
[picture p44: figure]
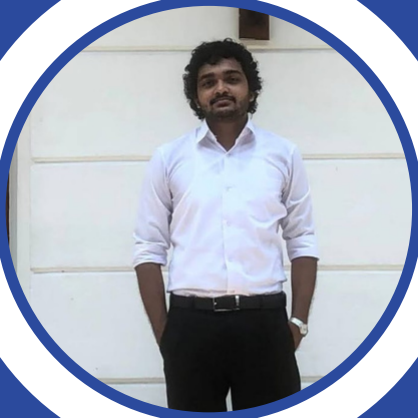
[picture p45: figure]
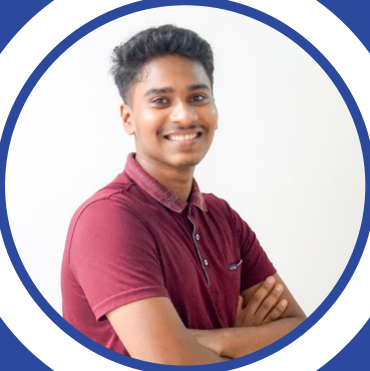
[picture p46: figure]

DINUKA | SANUJA | MIHIRAN | DANIDU

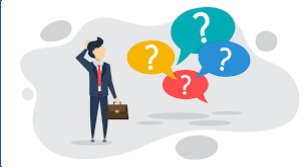
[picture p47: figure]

Slide 1

The world is rapidly advancing towards a future where smart technologies are becoming ubiquitous in our daily lives. However, despite this technological progress, there are still many devices and appliances that do not have smart capabilities. One such example is the power outlet. While there have been some attempts to create "smart" power outlets, the majority of them do not live up to the level of sophistication that we have come to expect from modern technology.

# The Need of A Smart Modular Power Outlet

# Hidden Problems in the Market

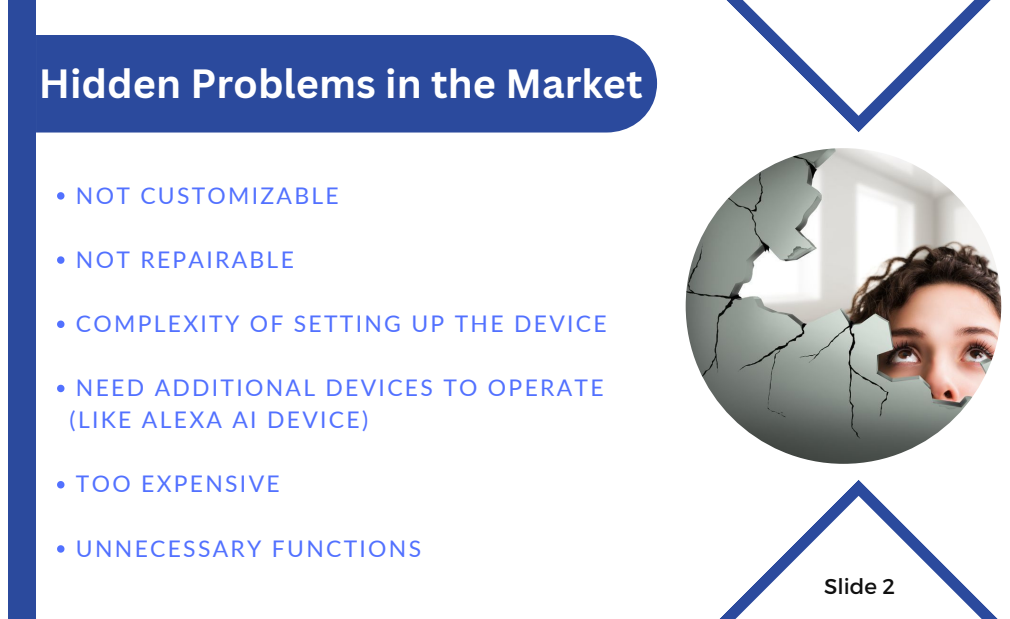
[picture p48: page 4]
NOT CUSTOMIZABLE; NOT REPAIRABLE; TOO EXPENSIVE; UNNECESSARY FUNCTIONS; Slide 2

COMPLEXITY OF SETTING UP THE DEVICE

NEED ADDITIONAL DEVICES TO OPERATE
(LIKE ALEXA AI DEVICE)

# Results of Our

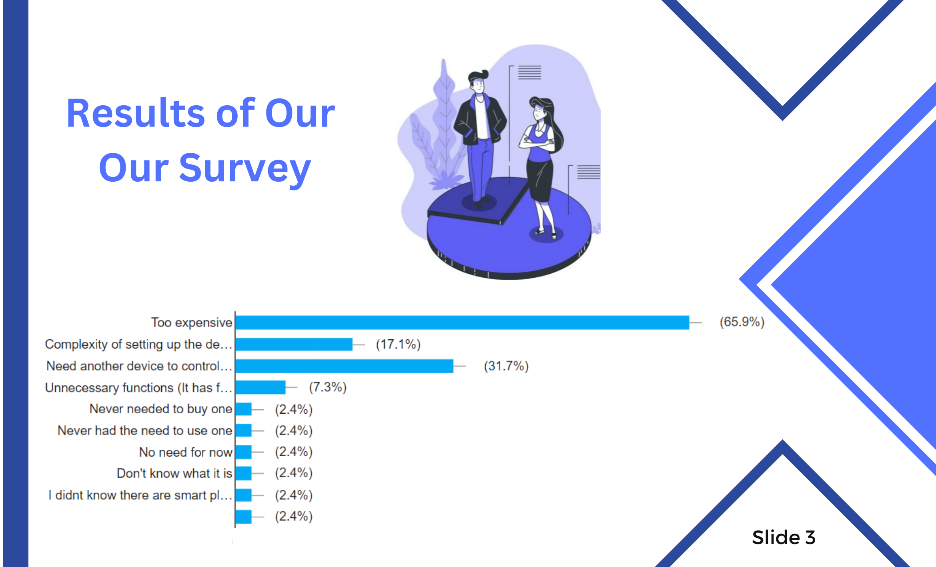
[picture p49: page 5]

# Our Survey

Slide 3

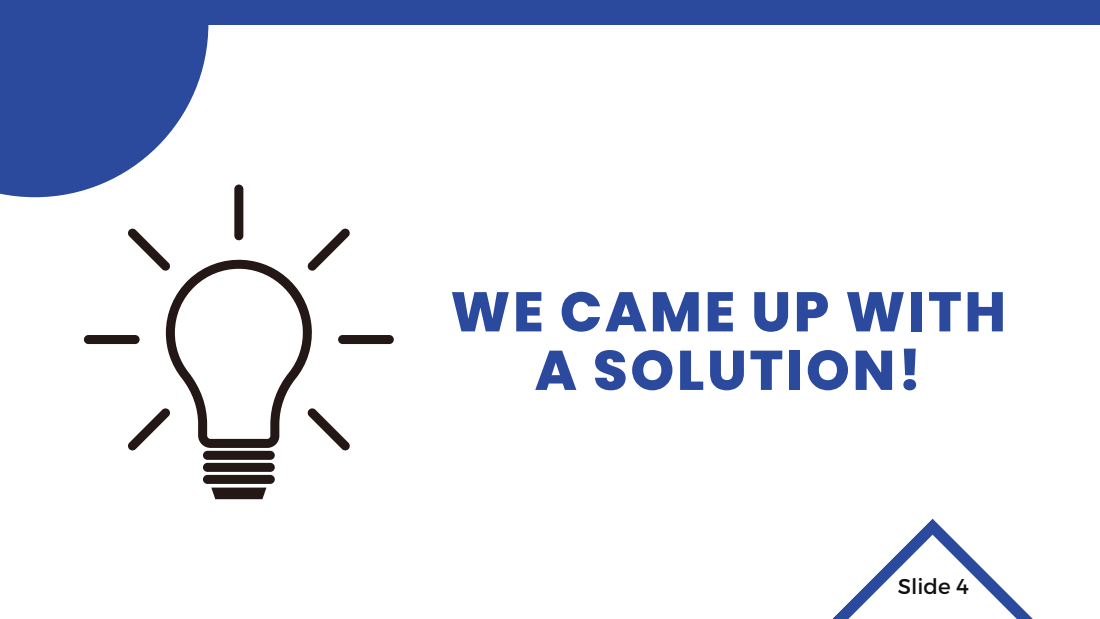
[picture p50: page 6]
Slide 4

WE CAME UP WITH
A SOLUTION!

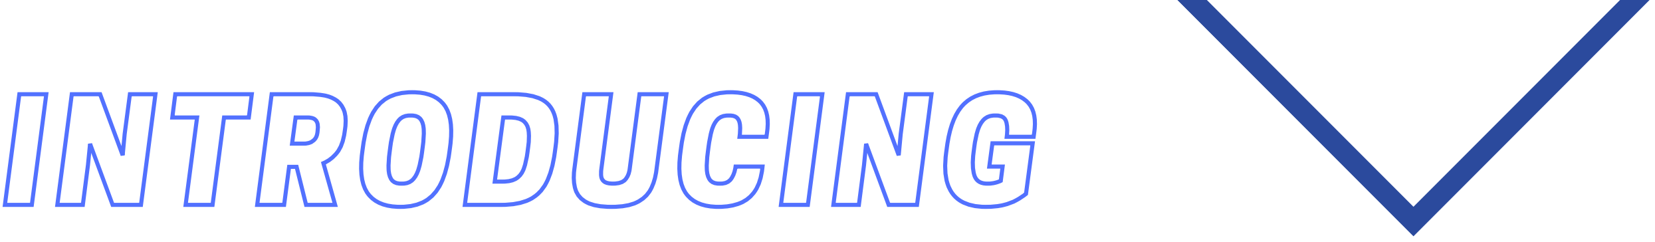
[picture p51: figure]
INTRODUCING

Slide 5

# PLUGSi

Smart Modular Power Outlet

### "The power outlet of the future! With our modular design, you can customize your outlet to fit your unique needs. Start with the base and add on as you go - it's the smartest way to power up!"

# TWO MAIN PARTS


Modules | Power Base

BLUETOOTH MODULE
TIMER MODULE
PIR MODULE

WIRELESS SWITCH
REMOTE MODULE

Slide 6

Control the output
based on the inputs from
the modules

# How we are

Modular; Slide 7

Unique? Unique? Unique?

We are using a standardize protocol to
communicate.

Power base will be affordable.

3rd Parties can develop modules.

Modules can be swapped based on the
interest.

# But How?


The solution we propose is a smart modular power outlet to which the user can attach modules as needed.

Slide 8

# MAXIMIZING CUSTOMER SUCCESS

Sales Strategy; Technical support. Warranty services. Customer education. Feedback channels.; Slide 9

After Sales Services

Provide product samples.
Negotiate terms.
Set clear expectations and goals.
Provide marketing support.

# MAXIMIZING CUSTOMER SUCCESS

Product Packaging; Marketing; Slide 10

We plan to implement the
following concepts into our
product packaging.
Product demonstration
Minimalist design
Interactive packaging
Eco-friendly packaging

Industrial Partnership
Attend industry events.
Create joint content.
Identify potential partners.
Reach out to potential
partners.
Social media campaign

Component | Price (Rs.)
74HC74 ic (D flip flop) | 70
5V single-channel Relay module | 75
AC to 5V dc converter | 285
4 ports | 4 x 30
Enclosure | 500
PCB | 140
3 Pins (Male, Female)For take 230 | 80
Other | 130
Totoal | Rs. 1400

# Budget - Power Base

Slide 11

### Selling Price

Rs. 2000

# Budget - Modules

Slide 12

### These are prices that we calculated for developments and price for production will be lower and the selling price will be much lower

Component | Price (Rs.)
NE555 ic | 30
PCB | 200
Toggle Switch | 20
Enclosure | 300
Other | 300
Total | Rs. 850
Component | Price (Rs.)
ATmega 328p | 1400
HC-06 Bluetooth Module | 1200
PCB | 200
Enclosure | 300
Others | 300
Total | Rs. 3400

HC06 Bluetooth Module

Selling Price Rs. 1200 | Selling Price Rs. 3700

Timer Module

Inter communication with in modules; AI , Programmable, and device-specific modules; Inter communication with outlets; Implement SPI protocol for communication; A magnetic port for user sastisfaction; A display to show power consumption by the utility; IMPROVEMENS; Future Improvements; Slide 13

# Others Views


Slide 14

"Remote controlled power
outlet is a great idea!!
I hate getting out of my
bed to switch on/off stuff." "Modular approach
is very
useful and powerful."

"I guess your approach is very practical sicnce the user can have the functionalities that he needed without paying
unnecessary amount of
money"


# THANK YOU!

### KOS Tronics

End Slide

# PLUGSi

Smart Modular Power Outlet

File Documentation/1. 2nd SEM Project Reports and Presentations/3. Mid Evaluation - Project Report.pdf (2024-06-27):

# PLUGSi

## Smart Modular Power Outlet

P r e s ent e d b y KOS T r oni c s

# About Us

We are a group of undergraduates from the Department of Electronics and Telecommunication Engineering, at University of Moratuwa.

We are pleased to announce the development of our latest innovation, a modular smart power outlet. Our primary objective with this product is to offer users complete control over their power outlets by employing a diverse range of modules.

Our smart power outlet is a result of tireless research and development, and we are thrilled to offer it to you. It features an extensive range of modular components that can be tailored to suit your precise requirements, all of which connect to a base.

Our product is designed to be flexible and adaptable, allowing it to grow and change alongside your needs. To achieve this level of flexibility, we have introduced each module separately, making our smart power outlet a versatile and customizable solution for all your power needs.

# Revolutionizing Smart Power Outlets

Not customizable
Not repairable
Complexity of setting up the device
Need additional devices to operate (like ALEXA AI device) Too Expensive
Unnecessary functions

Problems with existing solutions

We conducted a survey and this is the result

# Hidden Problems in Modern Culture

The world is rapidly advancing towards a future where smart technologies are becoming ubiquitous in our daily lives. However, despite this technological progress, there are still many devices and appliances that do not have smart capabilities. One such example is the power outlet. While there have been some attempts to create "smart" power outlets, the majority of them do not live up to the level of sophistication that we have come to expect from modern technology.

Many of these devices are simply glorified timers or remote switches, which can only turn appliances on and off at predetermined times or via a smartphone app. This lack of innovation in the power outlet space is surprising, given the potential benefits of smart power outlets. Despite these challenges, there are still some promising developments in the smart power outlet space. As technology continues to evolve and more people embrace the benefits of smart homes.


The solution we propose is a smart modular power outlet to which the user can attach modules as needed.

In our proposed solution, users can get the smart power outlet base for a low price and then add up the required and additional modules as needed.

Manufacturing a purpose specific solution can be costly because number of products is small but manufacturing a general solution that can be made purpose specific is ideal for that problem.

# We came up with a solution!

## But how..?

Power Base
Modules

The device is consisted of two main parts.

Power Base will be connected to a power outlet and any utility (device) can be connected the Power Base. The Power Base will control the AC supply to the device and provide power to modules. Power Base will have a port (interface) to communicate with the modules.
Bluetooth Module
Timer Module
PIR Module
Wireless Swicth / Remote Module

Modules can be attached to and detached from the Power Base. Modules will control the state of the Power base. Modules can have a variety of abilities based on their design. Multiple modules can be connected to the same Main Base. Some examples for Modules are,

Modules | Power Base

# Physical View


The module is designed to issue a command using a pulse signal, and it will perform a status check prior to generating the pulse signal. In the event that the power base has reserved a pulse, the base will modify the current state of the relay.

This functionality is achieved through the implementation of a pulse-based communication protocol and the integration of status monitoring and relay control mechanisms within the module's architecture.

Dimensions - 9 X 6 X 6 cm

### Block Diagram

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

# Maximizing Customer Success

## Key Considerations for Marketing, Sales, and After-Sales

### Product Packaging

Product demonstration: We will incorporate a product demonstration into the

environment.

packaging at the | back such as a small window explaining the basic
functionalities and | the steps of setting up the | device. Also we will include a
product manual inside the packaging as well.
Minimalist design: A | sleek, minimalist design | with a clean, simple look can
convey a sense of modernity and sophistication. We will use a white / blue finish with our logo, product name and the features included at the front.

Interactive packaging: We will incorporate an interactive element into the packaging, such as a QR code that takes the customer to an instructional video that provides further information and instructions for use.

Eco-friendly packaging: As consumers become more environmentally conscious, eco-friendly packaging is becoming increasingly popular. We will Consider using sustainable materials such as recycled cardboard or biodegradable plastics to reduce the impact of your product on the

services.; customer base.; with our marketing strategy.; Sales Strategy; Marketing; Social Media Marketing Email Marketing Influencer Marketing; Other Marketing strategies -

Attend industry events: Attend industry events such as trade shows, conferences, or workshops to network with potential partners and showcase our product.
Create joint content: Work with our partners to create joint content such as blog posts, videos, or webinars that showcase the benefits of our products or services.
Identify potential partners: Identify companies or organizations in the smart home or tech industry that have a similar target audience and complementary products or services. These will be companies that sell smart home devices, home security systems, or home automation

Reach out to potential partners: Reach out to potential partners and explain the benefits of a partnership. For example, we could co-create content, share social media posts, or offer joint promotions or discounts to each other's customers.

Our main marketing strategy will be Marketing through Industry Partnerships -
By partnering with other companies or organizations in the smart home or tech industry, we can leverage their audience and expertise to increase brand awareness, credibility and reach a wider

Provide product samples: Provide product samples to potential partners so they can see the quality and functionality of your product first-hand. This can help build credibility and increase the likelihood of them choosing to partner with your company.

Negotiate terms: Negotiate terms with your partners, such as pricing, distribution agreements, and marketing support. Establish clear expectations and goals upfront to ensure a successful partnership.

Provide marketing support: Provide marketing support to your | partners to help promote
your product. This could include providing product information, | marketing materials, and
training sessions.

We will try to sell our product through our partners and distributors so that it will be aligned

an additional fee.; power outlet.; After Sales Services

Technical support: | Offer technical support to customers who are
experiencing issues | with their smart modular power outlet. This will
include troubleshooting advice, repair services, or replacement parts.

Warranty services: Provide warranty services for our smart modular power outlet to give customers peace of mind. This could include a standard warranty that covers defects or malfunctions, or an extended warranty for

Customer education: Provide educational resources to help customers understand how to use and maximize the benefits of their smart modular

Feedback channels: Provide channels for customers to provide feedback and suggestions for improving our product. This can help us identify areas for improvement and provide a better customer experience.

Providing | after-sales | services can help build customer loyalty and increase
customer | satisfaction. | We | will be able to provide the following after sales
services for our smart modular power outlet :

Component | Price (Rs.)
74HC74 ic (D flip flop) | 70
5V single-channel Relay module | 75
AC to 5V dc converter | 285
4 ports | 4 x 30
Enclosure | 300
PCB | 140
3 Pins (Male, Female)For take 230 | 80
Shipping Cost + Others | 2350 + 120
Totoal | 1190
Component | Price (Rs.)
NE555 ic | 30
PCB | 200
Toggle Switch | 20
Enclosure | 300
Other | 300
Total | 850

# Budget

Component | Price (Rs.)
ATmega 328p | 1400
HC-06 Bluetooth Module | 1200
PCB | 200
Enclosure | 300
Others | 300
Total | 3400
Timer Module | HC06 Bluetooth Module

Power Base

## Selling Price

Rs. 2000

Selling Price Rs. 1100 | Selling Price Rs. 3700

*we have considered development costs only, production costs will be much more lower

Shipping Cost Rs.2350

# Task Allocation

Timer Module Enclosure Designing PCB Designing; Enclosure Designing 3D Printing Bluetooth Module; Sanuja; Dinuka; Mihiran Wickramarathne; Sanuja Rupasinghe

Danidu
PCB Designing & Printing
Enclosure Designing
Finance Handling

Mihiran
Base Designing
Communication protocols
Wireless Switch / Remote Module

Danidu Dabare Dinuka Madhushan

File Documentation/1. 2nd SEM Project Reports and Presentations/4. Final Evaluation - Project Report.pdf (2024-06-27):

# PLUGSi

## Smart Modular Power Outlet

P r e s ent e d b y KOS T r oni c s

# About Us

We are a group of undergraduates from the Department of Electronics and Telecommunication Engineering, at University of Moratuwa.

We are pleased to announce the development of our latest innovation, a modular smart power outlet. Our primary objective with this product is to offer users complete control over their power outlets by employing a diverse range of modules.

Our smart power outlet is a result of tireless research and development, and we are thrilled to offer it to you. It features an extensive range of modular components that can be tailored to suit your precise requirements, all of which connect to a base.

Our product is designed to be flexible and adaptable, allowing it to grow and change alongside your needs. To achieve this level of flexibility, we have introduced each module separately, making our smart power outlet a versatile and customizable solution for all your power needs.

# Revolutionizing Smart Power Outlets

Not customizable
Not repairable
Complexity of setting up the device
Need additional devices to operate (like ALEXA AI device) Too Expensive
Unnecessary functions

Problems with existing solutions

We conducted a survey and this is the result

# Hidden Problems in Modern Culture

The world is rapidly advancing towards a future where smart technologies are becoming ubiquitous in our daily lives. However, despite this technological progress, there are still many devices and appliances that do not have smart capabilities. One such example is the power outlet. While there have been some attempts to create "smart" power outlets, the majority of them do not live up to the level of sophistication that we have come to expect from modern technology.

Many of these devices are simply glorified timers or remote switches, which can only turn appliances on and off at predetermined times or via a smartphone app. This lack of innovation in the power outlet space is surprising, given the potential benefits of smart power outlets. Despite these challenges, there are still some promising developments in the smart power outlet space. As technology continues to evolve and more people embrace the benefits of smart homes.


The solution we propose is a smart modular power outlet to which the user can attach modules as needed.

In our proposed solution, users can get the smart power outlet base for a low price and then add up the required and additional modules as needed.

Manufacturing a purpose specific solution can be costly because number of products is small but manufacturing a general solution that can be made purpose specific is ideal for that problem.

# We came up with a solution!

## But how..?

Power Base
Modules

The device is consisted of two main parts.

Power Base will be connected to a power outlet and any utility (device) can be connected the Power Base. The Power Base will control the AC supply to the device and provide power to modules. Power Base will have a port (interface) to communicate with the modules.
Bluetooth Module
Reprogrammable Timer Module Set Timer Module
Wireless Switch

Modules can be attached to and detached from the Power Base. Modules will control the state of the Power base. Modules can have a variety of abilities based on their design. Multiple modules can be connected to the same Power Base. Some examples for Modules are,

Modules | Power Base

# Physical View

Power Base | Modules


Dimensions 4 x 6 x 6 cm

# Operating Concept


The module is designed to issue a command using a pulse signal, and it will perform a status check prior to generating the pulse signal. In the event that the power base has reserved a pulse, the base will modify the current state of the relay.

This functionality is achieved through the implementation of a pulse-based communication protocol and the integration of status monitoring and relay control mechanisms within the module's architecture.

Block Diagram of the Power Base

Schematic of the Power Base

First the | plan was to use | two different pulses for on and off but then we
decided to use a single | pulse. The modules check the status of the base and
decide whether to send the pulse or not. This was achieved by using a 4 NAND IC inside the Base. This is the design we implemented.
Alternative solution | is | to | use separate links to on and off or to use two
different pulses. But we decided our solution is good because NAND IC was not a high cost, and it doesn’t consume much power. The drawback of it was the IC is needed for every module.

We generated pulses with a NOR gates. Theoretical pulse width is 1.4ms but it was around 1.8ms when measured. We used QUAD NOR IC and it was possible to make two different pulse generators with it. Some modules needed two independent pulse generators, but some needed one. But we used the same set of ICs for all the modules considering their low cost.

Modules also has their own circuits to achive their designated tasks.

### Power Consumption

Base
With Relay on - 330mW
Stand By - 3mW

Wireless Module - 69.6mW
Bluetooth Module - 200mW

We used 3.5W power supple

There is a D flip-flop in the base, and it controls the relays. There is a transistor circuit to prevent relay taking power from D flip-flop. The command channels from the modules are connected to the clock pin of the D flip-flop.

Base

Commiuncation

Expense | Price (Rs.)
PCB Printing PCB - 6 | 15,000
Enclosure Printing Power Base - 1 Modules - 4 | 15,000
Electronic Components | 15,000
Other Costs Transportation Drill Soldering Iron Other Accessories | 10,000
Total | 65,000

# Development Costs

Component | Price (Rs.)
74HC74 ic (D flip flop) | 70
5V single-channel Relay module | 75
AC to 5V dc converter | 285
4 ports | 4 x 30
Enclosure | 1500
PCB | 1500
3 Pins (Male, Female)For take 230 | 80
Other | 300
Totoal | 3940
Component | Price (Rs.)
NE555 ic | 30
PCB | 1500
Toggle Switch | 20
Enclosure | 1500
Other | 300
Total | 3350

# Budget

Component | Price (Rs.)
ATmega 328p | 1400
HC-06 Bluetooth Module | 1200
PCB | 1500
Enclosure | 1500
Others | 300
Total | 5900
Timer Module | HC06 Bluetooth Module

Power Base

*we have considered development costs only, actual production costs will be much more lower.

Component | Price (Rs.)
Timer module | 1000
PCB | 1500
switches | 200
Enclosure | 2000
Other | 300
Total | 5000
Component | Price (Rs.)

Wireless
transmitter and reciever | 1000
PCB | 1500
Enclosure | 2000
Others | 300
Total | 4800
Reprogrammable Timer Module | Wireless Switch

*we have considered development costs only, actual production costs will be much more lower.

Since the product packaging is the first interaction a customer has with our product, it's important to make it eye-catching and informative while also aligning with our brand identity. We plan to implement the following concepts into our product packaging.

# Maximizing Customer Success

## Key Considerations for Marketing, Sales, and After-Sales

### Product Packaging

Product demonstration: We will incorporate a product demonstration into the packaging at the back such as a small window explaining the basic

environment.

functionalities and | the steps of setting up the | device. Also we will include a
product manual inside the packaging as well.
Minimalist design: A | sleek, minimalist design | with a clean, simple look can
convey a sense of modernity and sophistication. We will use a white / blue finish with our logo, product name and the features included at the front.

Interactive packaging: We will incorporate an interactive element into the packaging, such as a QR code that takes the customer to an instructional video that provides further information and instructions for use.

Eco-friendly packaging: As consumers become more environmentally conscious, eco-friendly packaging is becoming increasingly popular. We will Consider using sustainable materials such as recycled cardboard or biodegradable plastics to reduce the impact of your product on the

services.; customer base.; with our marketing strategy.; Sales Strategy; Marketing; Social Media Marketing Email Marketing Influencer Marketing; Other Marketing strategies -

Attend industry events: Attend industry events such as trade shows, conferences, or workshops to network with potential partners and showcase our product.
Create joint content: Work with our partners to create joint content such as blog posts, videos, or webinars that showcase the benefits of our products or services.
Identify potential partners: Identify companies or organizations in the smart home or tech industry that have a similar target audience and complementary products or services. These will be companies that sell smart home devices, home security systems, or home automation

Reach out to potential partners: Reach out to potential partners and explain the benefits of a partnership. For example, we could co-create content, share social media posts, or offer joint promotions or discounts to each other's customers.

Our main marketing strategy will be Marketing through Industry Partnerships -
By partnering with other companies or organizations in the smart home or tech industry, we can leverage their audience and expertise to increase brand awareness, credibility and reach a wider

Provide product samples: Provide product samples to potential partners so they can see the quality and functionality of your product first-hand. This can help build credibility and increase the likelihood of them choosing to partner with your company.

Negotiate terms: Negotiate terms with your partners, such as pricing, distribution agreements, and marketing support. Establish clear expectations and goals upfront to ensure a successful partnership.

Provide marketing support: Provide marketing support to your | partners to help promote
your product. This could include providing product information, | marketing materials, and
training sessions.

We will try to sell our product through our partners and distributors so that it will be aligned

an additional fee.; power outlet.; After Sales Services

Technical support: | Offer technical support to customers who are
experiencing issues | with their smart modular power outlet. This will
include troubleshooting advice, repair services, or replacement parts.

Warranty services: Provide warranty services for our smart modular power outlet to give customers peace of mind. This could include a standard warranty that covers defects or malfunctions, or an extended warranty for

Customer education: Provide educational resources to help customers understand how to use and maximize the benefits of their smart modular

Feedback channels: Provide channels for customers to provide feedback and suggestions for improving our product. This can help us identify areas for improvement and provide a better customer experience.

Providing | after-sales | services can help build customer loyalty and increase
customer | satisfaction. | We | will be able to provide the following after sales
services for our smart modular power outlet :

Enclosure Designing & Printing

PCB Designing & Printing

Sanuja

Dinuka

# Task Allocation

PCB Designing & Printing

Circuit Designing for Power Base & Modules

Danidu

Mihiran


A.D.T. Dabare
210089P


I.D. Madhushan
210349N


N.P.S.S. Rupasinghe
210549D


M.P. Wickramarathne
210703V

# Way Ahead

After some arguments we decided to create our own port. We knew it would not be a easy task but we wanted to take the challenge.

The 3D printed port had some contact issues therefore we could not use it because it was not providing stable connections to the modules. We tried a different approach. It was also not promising. Therefore in the demo we had to switch back to an available port.

There was another error in the plug pins too. It was also not contacting properly with the Power Base due to some errors in the dimensions of the printed Base.

First we must correct these technical faults. We are planning on using magnetic port for the connections. We have decided to use already available ports instead of designing our own. We must do some modifications to the design to accompany this.

We believe our circuits are robust enough to go to the next phase. We are planning on using SMD components.

We believe the overall enclosure design is good for the next phase despite some difficulties encountered with the port and the power pins.

Overall we believe our prototype was a success and there is a way ahead.

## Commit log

2024-06-27 data in main repos are added to this
    Enclosure
    [220ACto5VDC.SLDPRT, Base_Back.SLDPRT, Base_Front.SLDPRT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]
2024-06-27 data in main repos are added to this
    PCB
    [Copy of PCB1.PcbDoc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]
2024-06-27 ar unity app added from original repo
    [RoundedCube.obj]
